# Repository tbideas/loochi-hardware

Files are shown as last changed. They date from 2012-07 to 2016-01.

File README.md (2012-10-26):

Hardware source files for TBIdeas lamp
======================================

This github project contains the source file for the different revisions and prototypes of our smart lamp called Illumi and then Loochi.

## License

    Copyright 2012 - TBIdeas.com
    Distributed under the CC-BY-SA license.
    http://creativecommons.org/licenses/by-sa/3.0/

## Loochi v0.4

Third prototype.

This one is very similar to 0.3 but instead of a Bluegiga BLE112 module, we use an Aircable module with its generic firmware (so it does not need any programming). This module is not yet publicly available but will be very soon. Until then, you can contact us if you would like to get some.

In this design, we have also removed the npn/pnp transistors that were used to drive the mosfet. We wanted to compare the performance with and without them.

The communication protocol is labeled as I2C between the BLE module and the attiny but you can also do SPI. We have not really decided which one we will stick to.

### Known problems and limitations

This board was designed before we had time to assemble the 0.3 so the same problem applies on the LED pads, and connections.

## Loochi v0.3

Second complete prototype designed and built by us.

There is only one board with the LED soldered directly on the board. The PCB is intended to be an aluminium core PCB. For prototypes we have used traditional FR4 boards (from the awesome oshpark.com). In any case you absolutely need a pretty big heatsink on the other side of the board.

This board design is a major rework over the previous version. The main goal was to reduce manufacturing cost so that more people could enjoy Loochi. Another major design decision was to drop Wifi. We could write a lot about that but the biggest arguments were: (1) Wifi seriously increases the costs of the solution and (2) the efforts required by the user to set-up a Wifi lamp are important.

Main characteristics:
 * One ATTiny 861A is used to control the current going through the LED and adjust the brightness
 * One BLE112 module from Bluegiga is used for Bluetooth Low Energy communication with the app, it acts as an SPI Master to the Attiny
 * There is no more dedicated chip for the LED PWM (to reduce costs)
 * Ledengin 10W RGGB Led soldered directly on the PCB
 * Funny fact: the board radius is 3.1415925 cm

You will find more information on how this board works in the source code of the AVR. Several versions are provided (with graduating levels of complexity).

We also plan to do a video to explain how it works. If you are interested, let us know and it will probably be done quicker!

### Known problems on the board layout

There are a few known problems on this PCB:
 * The LED footprint is wrong: the first green LED is backwards (stupid mistake when linking pads and signals)
 * The schematic uses the RESET pin of the uController but we decided later on to change that, the mapping used in the software is BSENSE connected to PB5 and BPWM connected to PB4 (which means the Blue PWM output is inverted but allows us to keep the RESET pin free)
 * The BLE112 module is very sensitive to the quality of the power supply, add an RC filter on its VCC
 * Remove Q4 and short its source and drain (otherwise you will get a shortcut) - Warning: this removes the reverse voltage protection

If you want to make your own, we suggest that you fix those before getting the board manufactured or wait for a new design from us that would not have those problems. Another option is always to cut some traces and put some small wires. This is what we have done.

## Illumi v0.2

__Note: We used to call this version Illumi - dont be surprised in the documentation and source code__

This is the first complete prototype completely designed and built by us.

It is a dual-board design: a board with the micro-controller and the Wifi card, and another board with the LED drivers.

Features of the motherboard:

 * Arduino-Leonardo clone running at 8Mhz - Programmable via a ICSP connector or through the USB cable (once the bootloader has been burnt). You can use the Arduino IDE to program it.
 * Wifi module RN-171 from Roving Networks with a wire antenna
 * Bluetooth 4 Low Energy BLE112 module from Bluegiga
 * Only 75mm by 50mm
 * Switching 3.3 V power supply
 
Features of the LED driver

 * Input voltage from ~5V to 20V (depends on the type of LED you want to power) - Compatible with all sorts of high power LEDs
 * Three LT3518 swiching regulator for a 700mA constant current source to drive one RGB led
 * PWM inputs to control the brightness of each component: Red, Green, Blue
 * Shutdown pin to turn off the regulators and save power
 * Three temperature sensors to measure the board temperature

### Files

 * illumi-motherboard.sch: Eagle Schematic for the motherboard
 * illumi-motherboard.sch: Eagle Board for the motherboard
 * illumi-leddriver.sch: Eagle Schematic for the LED Driver
 * illumi-leddriver.sch: Eagle Board for the LED Driver
 * illumi-leddriver.asc: LTSpice simulation for one LT3518 channel 
 * illumi-v0.2-bom.csv: Bill of material - Detailed list of parts with Mouser reference number, price, etc

### Other resources

 * Source code for the motherboard is available in the Github project named "illumi"
 * Configuration files for the Arduino environment to program this board is in the project named "illumi-arduino"
 * Blog articles:
 ** [3D renderings][blog-board3d]
 ** [Pictures of the assembled board][blog-v0.2]

### Known problems and limitations

 * On the motherboard, you must not solder R16 and bridge the pads instead. The idea was to build a low-pass filter with R16 and C13 but the voltage drop on AVCC is too high and the chip is not programmable with R16 in place. Check out [this discussion on electronics stackexchange][stackexchange-avcc] for more info.
 * The LED driver includes a LM317 to provide 3.3V to the three LT3518. Although they dont use much current, bringing a 20V input to 3.3V incurs some serious heat dissipation on the LM317. It works so far but the next designs will use the motherboard voltage regulator for 3.3V

## Illumi v0.1

This is a very cheap to build linear current source for high power RGB LEDs. Find out more and read more on the [blog article][blog-v0.1]. 

## Illumi v0.0

This is the simplest way to drive an RGB light. Those files were produced to prepare a [blog post introducing development for Illumi][blog-v0.0].

## Let's stay in touch!

We hope you will find this information useful! We are open-sourcing all of this in the hope that it will be useful to someone else - if it is, or if you have any question, please contact us: contact THE_AROBASE tbideas.com.

[blog-v0.0]: http://www.tbideas.com/blog/illumi-101-iphone-controlled-rgb-light/
[blog-v0.1]: http://www.tbideas.com/blog/build-an-arduino-shield-to-drive-high-power-rgb-led/
[stackexchange-avcc]: http://electronics.stackexchange.com/questions/36167/understanding-the-avcc-pin-wiring-on-arduinoleonardo-low-pass-filter
[blog-v0.2]: http://www.tbideas.com/blog/some-pictures-of-our-latest-prototype/
[blog-board3d]: http://www.tbideas.com/blog/design-of-the-led-driver/
[contact]: contact@tbideas.com

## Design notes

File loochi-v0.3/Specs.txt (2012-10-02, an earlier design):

Designing Loochi v0.3
=====================

So I am starting work on the next prototype and here are the main characteristics I am going to focus on.

Characteristics:

 * Works for different types of LEDs: 10W to 40W at least, more if possible
 * Wide range of input voltage: min 6v (?) to 20V to drive those LEDs
 * Wifi card on board
 * Wifi configurable (???) <= tbd - sdcard? or better, sound jack!
 * Cheap - cheap - cheap - Should cost less than $60 (including LED) so that we can sell it for 150$

 * The firmware should be easy to upgrade
   -> USB connection with the bootloader (a little complicated)
   -> Custom bootloader that uses the RN171 to download firmware - quite complicated too
   -> Custom bootloader that loads from a SD Card the firmware

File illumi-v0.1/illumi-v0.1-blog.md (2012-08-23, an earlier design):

# Build an Arduino shield to drive high-power RGB LED

If you have read our [previous post][previous-post], you know how easy it is to connect a RGB led to an Arduino micro-controller. It is amazing to put this thing in a corner of your room and change the color during the night but chances are ... you will be the only one impressed by that.

The [very basic LED][datasheet] we used in our previous post has a power of 45mW (go ahead, take the [datasheet][datasheet] and do the math, it is an interesting exercice, post your results below!) and generates less than one lumen of [luminous flux][lumen]. This is not enough to light anything so you will quickly want to use much more powerful LEDs.

In this post, we will see how to build a very cheap linear LED driver and plug it to our Arduino so that you can actually drive high power RGB LED with the same software we used last time. This time, it gets impressive!

<!--more-->

# Choosing an high-power LED

For a while, high power LEDs were 1W or 3W LEDs. Nowadays, you can easily find 10W, 40W or [90W][lzp]. These are the types of LEDs we will focus on today. Because the bigger the better, especially whey you are building interior lighting fixtures like [Illumi][illumi]. 

The most important characteristics to look at are:

* What is the forward voltage of the diode: You will need to supply the LED with at least that voltage;
* What is the forward current of the diode: This is the current that you will need to supply to the diode. This needs to be very carefully regulated because if you let the current go to high, it will burn the LED. That's why we will build a constant current power supply;
* How will I get heat out of the LED.

And then of course, you will look at the light color, or in our case, the light colors because we will be working with RGB lights. Most of what we say might be adapted for single-color LED or four-colors LEDs.

We like the LEDs from LedEngin and for today's purpose, we will use a [LZ4-00MC00 RGB LED]. We highly recommend that you purchase the one that is already soldered onto a small thermal PCB that will help with heat dissipation. You can [find it on mouser.com][mouser-lz4] for $15.

This LED (like all multi-colors LEDs) is actually several LED dice on one chip. If you take a look at the [datasheet][lz4-datasheet], you will see that the maximum forward voltage for the red, green, and blue dices are 2.96V, 8.32V, 4.48V (the forward voltage for green is actually much higher because there are two green dices in series). We also learn from the datasheet that the nominal forward current is 700 mA, therefore the total power of the LED is 2.96*0.7+8.32*0.7+4.48*0.7=11W.

That is pretty nice compared to our previous sub-watt LED or traditional 1W or 3W led!

Of course, you can pick from other manufacturers, Cree and OSRAM Semiconductors are famous LED manufacturers. Tell us about your experiments in the comments!

# Choosing a current source

The usual technique of putting a current limiting resistor on this type of LED will not work for two reasons. The first one is that the heat dissipated by this resistor would be huge (`P = I * U = 700mA * (Vin - Vf)` = a few watts) but mostly the forward voltage will decrease as the LED heats up and therefore the voltage on the series resistor will be increased which will in turn increase the intensity of the current and the light will not be stable at all. 

You could go on google and purchase a current source but they are usually kind of big and very expensive ($20). Knowing that we need three of them, we ruled this solution out.

So the best solution is to build your own, and we will see how to build one for a couple of dollars.

# A simple linear current source

The schema we introduce here uses a mosfet transistor that is controlled by a feedback mechanism through a current-sense resistor. It is heavily inspired by [Dan Goldwater][dangoldwater] ([MonkeyLectric][monkeylectric]) work posted on [Instructables][instructables].

Linear current source

The parts on this schematic are available for a few dollars. You can replace the BUZ71 by another MOSFET N-channel transistor in a TO220 package. Make sure it can switch 40V to be on the safe side.
For an RGB LED, we will build this three times: once for each channel.

## Let's discuss the schematics

When the PWM input (which will be driven by your micro-controller) is low, then Q1 is not conducting and nothing happens. The LED does not get any current and does not light up.

Things get interesting when you raise the PWM input HIGH (+5V), at this point current will start to flow through R1 and the gate of Q1 and it will let current flow from the source to the drain, therefore turning on the LED.

As current flows through the LED, the voltage drop of R2 increases (remember, U=RI) and when it reaches 0.5V (the forward junction drop of T1),  T1 will start conducting and current from R1 will flow through T1 instead of flowing through Q1, which will reduce the current going through Q1 and the LED.
This circuit will stabilize so that the voltage on R2 is the forward junction drop of T1 and that is how we can control the current going through the LED.

This is a very simple but very efficient schematics that you can use to power any type of LED.

## Setting the current through the LED

One of the crucial component on this schematic is R2. In our example R2 is 0.82 ohm which means that the current in R2 and the LED will reach 610mA (0.5V / 0.82ohm) before it starts turning on T1.
For 610mA, the power dissipated by R2 will be around 0.4W make sure to get a 1/2W or 1W resistor!

Depending on the maximum current you want in your LED, you will adapt the value of R2.

## Heat

If you look at voltage in the circuit, you can easily see that:

    V+ = Vled + Vq1 + Vr1

In this formula, we know V+, Vled and Vr1. V+ is your input voltage, Vled is the forward drop of the LED and Vr1 is 0.5V, the voltage needed to start turning on T1. So let us rewrite the formula as:

    Vq1 = V+ - Vled - Vr1

With an input voltage of 12V and a forward drop of 9V, we will have:

    Vq1 = 12 - 9 - 0.5 = 2.5V
    
We also know that the current going through the circuit is 610mA, therefore the power dissipated in Q1 is:

    Pq1 = Vq1 * Iq1 = 1.5W

## Best case scenario

From the formula above, we can deduce that the circuit is very efficient when Vq1 is equal to 0V, that is when V+ is equal to the forward voltage drop of the LED plus 0.5V. Anything above that on the input will be dissipated as heat in Q1.

Do note also that as things heat up, the forward voltage of the led will reduce a little bit, as well as T1 junction forward voltage (a few hundreds of milli-volts).

## Powering RGB Leds

Let's get back to the value of our LED. We have seen that the forward voltage is not the same for all colors. But you will very likely have only one power supply providing one common voltage to all the LEDs. Therefore there will be some heat dissipation and the bigger the difference in forward voltage, the bigger will be the heat dissipation.

For the LED we suggested above, you can choose to not put both green LEDs in series and power only one, this will reduce the voltage drop difference between red, green and blue and will avoid wasting too much power in the red and blue current sources.

# Build your Arduino high power RGB led shield

So now that we have a schematics that works (I hope you have tried it on your experimentation boards!), you can turn that into an Arduino shield with just a little effort. 

Here is an exemple of what it might look like on a pre-etched PCB:

Arduino High power LED shield

Note that I have added heatsinks (and thermal paste) to the mosfet transistors. Even a few watts of power dissipated will heat the transistor pretty fast. Without heatsinks, they will not last long.

# More power!

If you are using higher power LEDs (or just more LEDs in series), the current will probably be the same but the voltage drop will be higher (that is because high power LEDs are actually more LEDs in series). Therefore the difference in drop between the different color will be even bigger and you will not be able to power them all from the same power supply. You have reached the limit of our linear current source.

The next step is to use a switching power supply that will be much more efficient, whatever the input voltage is. Our [design for Illumi v0.2][illumi-driver-v0.2] provides exactly that!

[previous-post]: http://www.tbideas.com/blog/illumi-101-iphone-controlled-rgb-light
[datasheet]: https://www.sparkfun.com/datasheets/Components/YSL-R596CR3G4B5C-C10.pdf
[lumen]: http://en.wikipedia.org/wiki/Lumen_(unit)
[lzp]: http://www.ledengin.com/products/emitters#LZP
[illumi]: http://www.tbideas.com
[mouser-lz4]: http://www.mouser.com/ProductDetail/LedEngin/LZ4-20MC00/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
[lz4-datasheet]: http://www.ledengin.com/files/products/LZ4/LZ4-00MC00.pdf
[instructables]: http://www.instructables.com/id/Circuits-for-using-High-Power-LED-s/step8/a-little-micro-makes-all-the-difference/
[dangoldwater]: http://www.instructables.com/member/dan/
[monkeylectric]: http://www.monkeylectric.com/
[illumi-driver-v0.2]: http://www.tbideas.com/blog/design-of-the-led-driver/

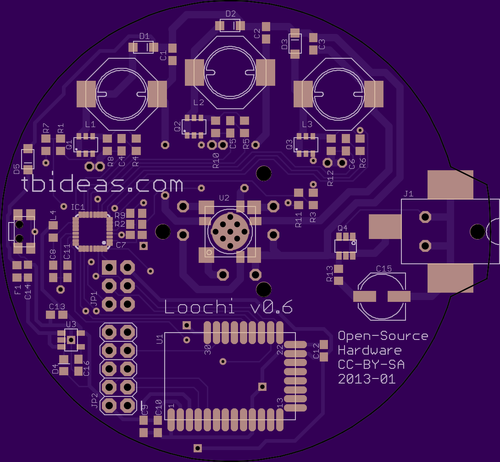
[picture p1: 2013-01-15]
loochi-v0.6/eagle/laenpcb-20130103a/board-top.png

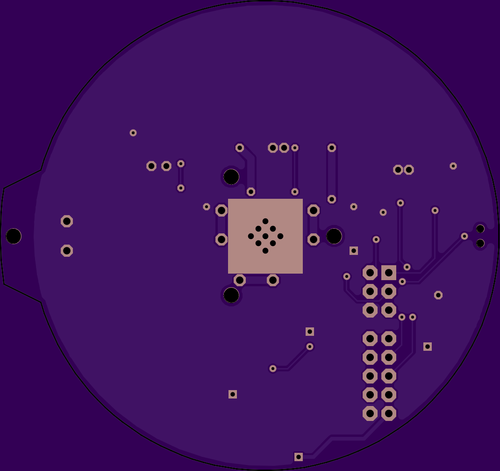
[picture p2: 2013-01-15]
loochi-v0.6/eagle/laenpcb-20130103a/board-bottom.png

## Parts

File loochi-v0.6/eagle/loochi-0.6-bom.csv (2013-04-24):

Part | Description | Package | Manufacturer | Mnf. Ref. | Mouser Ref | Qty | Price per unit ($) | Price /1000
C1,C2,C3 | 4.7uF | C-EUC0603 |  |  | 603-CC603KRX5R6BB475 | 3 | 0.09 | 0.023
C4,C5,C6,C16 (was C17) | 10nF | C-EUC0603 |  |  | 77-VJ0603Y103KXAAC | 4 | 0.06 | 0.016
C7,C8,C11,C14 | 0.1uF | C-EUC0603 |  |  | 77-VJ0603Y104JXJPBC | 4 | 0.06 | 0.012
C9,C10,C12 | 1uF | C-EUC0603 |  |  | 77-VJ0603V105MXQPBC | 3 | 0.06 | 0.009
C13 (was C14) | 10u | C-EUC0603 |  |  | 810-C1608X5R0J106M | 1 | 0.12 | 0.053
C15 (was C16) | 100uF | CPOL-EUD |  |  | 598-AVE107M25X16T-F | 1 | 0.13 | 0.066
D1,D2,D3,D5 | Schottky PMEG4010CEH | SOD123F |  |  | 771-PMEG4010CEH-T/R | 3 | 0.11 | 0.081
D4 | Schottky0603 | D0603 | Bourns |  | 652-CD0603-B00340 | 1 | 0.12 | 0.06
F1 | MPZ1608 | R-EU_R0603 |  |  | 810-MPZ1608S221A | 1 | 0.05 | 0.019
IC1 | ATTINY61M | ATTINY61M | MLF32 |  | 556-ATTINY861V10MU | 1 | 3.03 | 1.72
J1 (was J2) | SMD Power connector | POWER-JACK |  | KLDXSMT30202BTR | 806-KLDXSMT30202BTR | 1 | 1.61 | 1.05
JP1 (was J1) | SPI_PRG | AVR_SPI_PRG_6NS | 2X3-NS |  | 649-68602-406HLF | 1 | 0.12 | 0
JP2 | Molex 5x2 |  |  |  | 649-68602-110HLF | 1 | 0.3 | 0.15
L1,L2,L3 | SRU1038-101Y | L-USBOURNS-SRU1038 |  |  | 652-SRU1038-101Y | 3 | 0.58 | 0.32
L4 | 10uH | L-USL0603 |  |  | 810-MLZ1608M100W | 1 | 0.08 | 0.037
Q1,Q2,Q3 | PMN25ENSOT457 | PMN25ENSOT457 |  |  | 771-PMN25EN,115 | 3 | 0.14 | 0.095
Q4 | FDC654P | SUPERSOT6 | Fairchild Semi. | FDC654P | 512-FDC654P | 1 | 0.25 | 0.12
R1,R2,R3 | 10 | R-EU_R0603 |  |  | 652-CR0603-FX10R0GLF | 3 | 0.04 | 0.008
R4,R5,R6,R7,R9,R11 | 10k | R-EU_R0603 |  |  | 652-CR0603-FX1002HLF | 6 | 0.04 | 0.008
R8,R10,R12 | 0.1 | R-EU_R0603 |  |  | CRL0603-FW-R100ELF | 3 | 0.08 | 0.054
R13 (was R15) | 2 | R-EU_R0603 |  |  | 301-2.0-RC | 1 | 0.03 | 0.013
S1 |  |  |  |  | 611-KMS221GLFS | 1 | 0.29 | 0.25
U1 | Ble 112 |  |  |  | 603-BLE112-A | 1 | 17.5 | 15.9
U2 (was U1) | LZ4-00MC00 |  | Ledengin | LZ4-00MC00 | 897-LZ400MC00 | 1 | 11.52 | 9.25
U3 (was U$2) | LP2985 | LP2985 |  |  | 595-LP2985-33DBVR | 1 | 0.46 | 0.192
Heatsink |  |  | Lighting Science Group | HS-4075-0345 | 599-HS-4075-0345 | 1 | 19.21 | 15.99
Total |  |  |  |  |  |  | 58.84 | 46.8

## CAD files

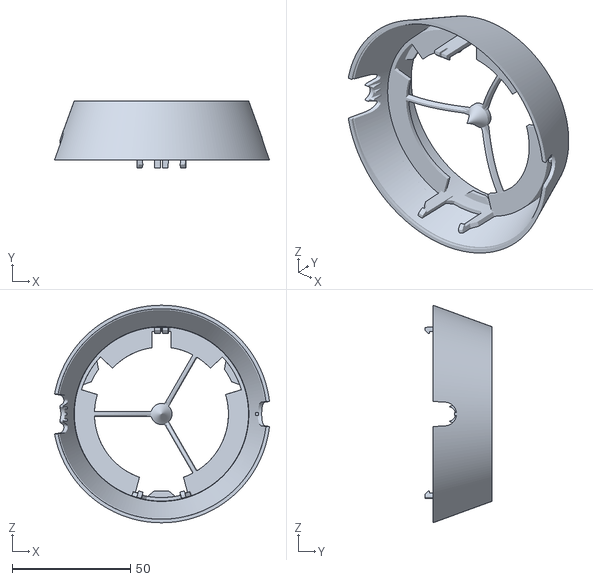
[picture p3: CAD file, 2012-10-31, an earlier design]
loochi-v0.4/Plastic/Loochi_Design/ShadeMount_E.STL
90.9 x 28.5 x 92.0

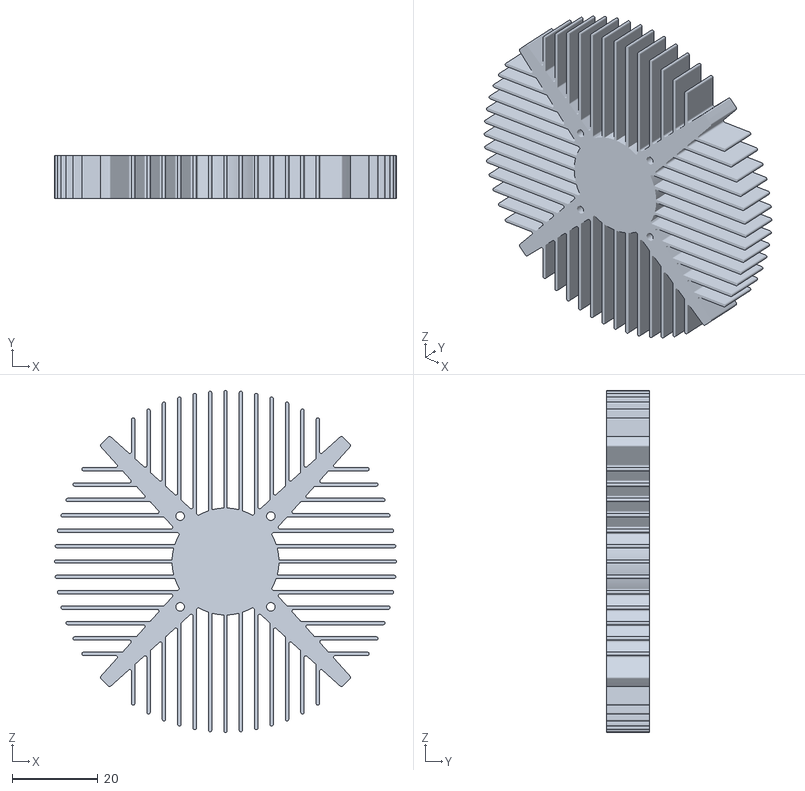
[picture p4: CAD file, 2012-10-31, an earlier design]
loochi-v0.4/Plastic/Loochi_Design/HeatSink_E.STL
80.0 x 10.0 x 80.0

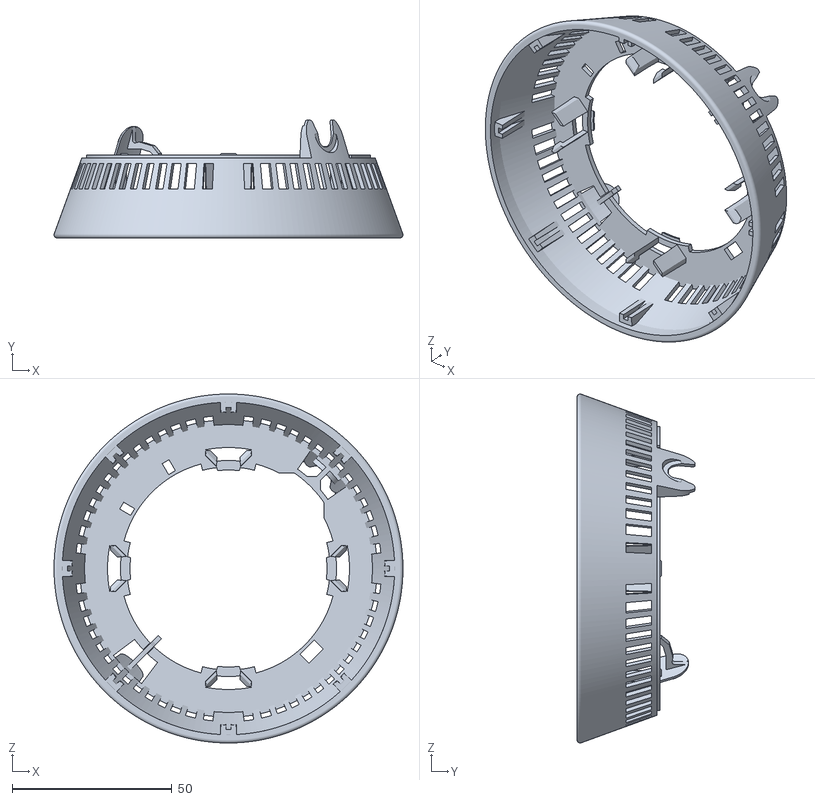
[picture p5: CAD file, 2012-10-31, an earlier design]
loochi-v0.4/Plastic/Loochi_Design/Bridge_E.STL
109.3 x 37.0 x 109.3

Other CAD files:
loochi-v0.6/plastic/loochi.f3d

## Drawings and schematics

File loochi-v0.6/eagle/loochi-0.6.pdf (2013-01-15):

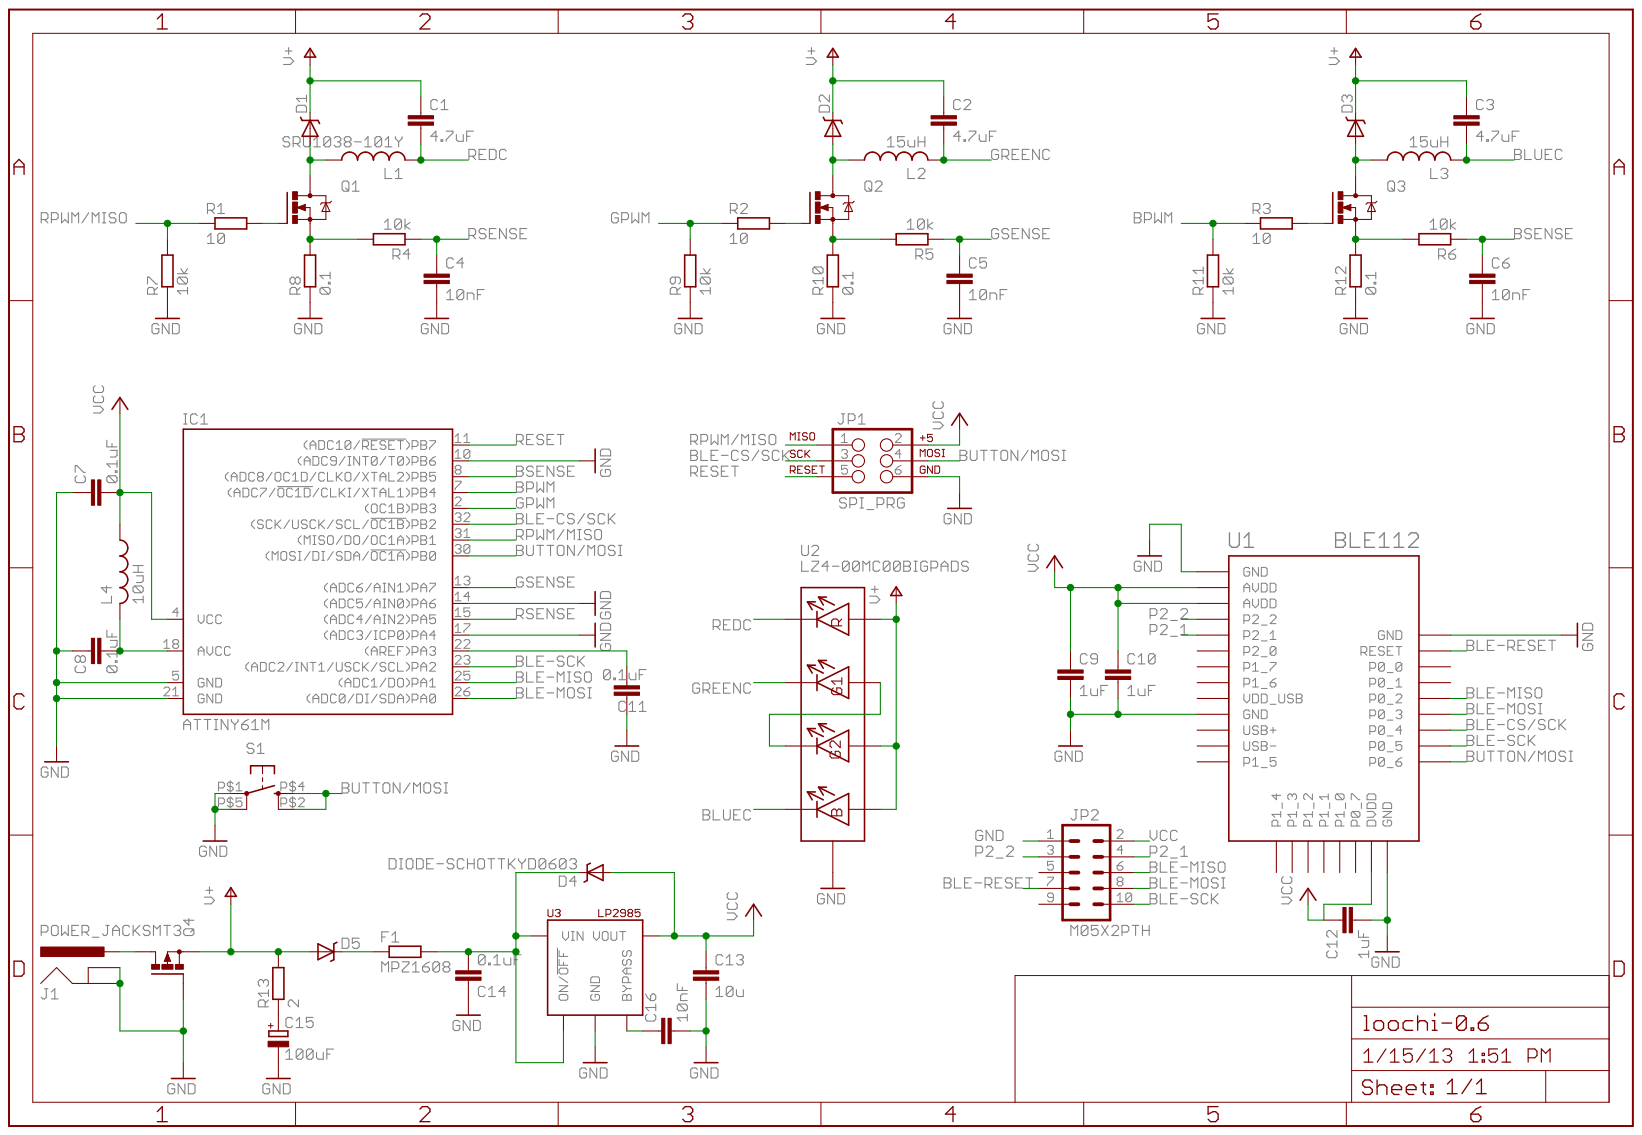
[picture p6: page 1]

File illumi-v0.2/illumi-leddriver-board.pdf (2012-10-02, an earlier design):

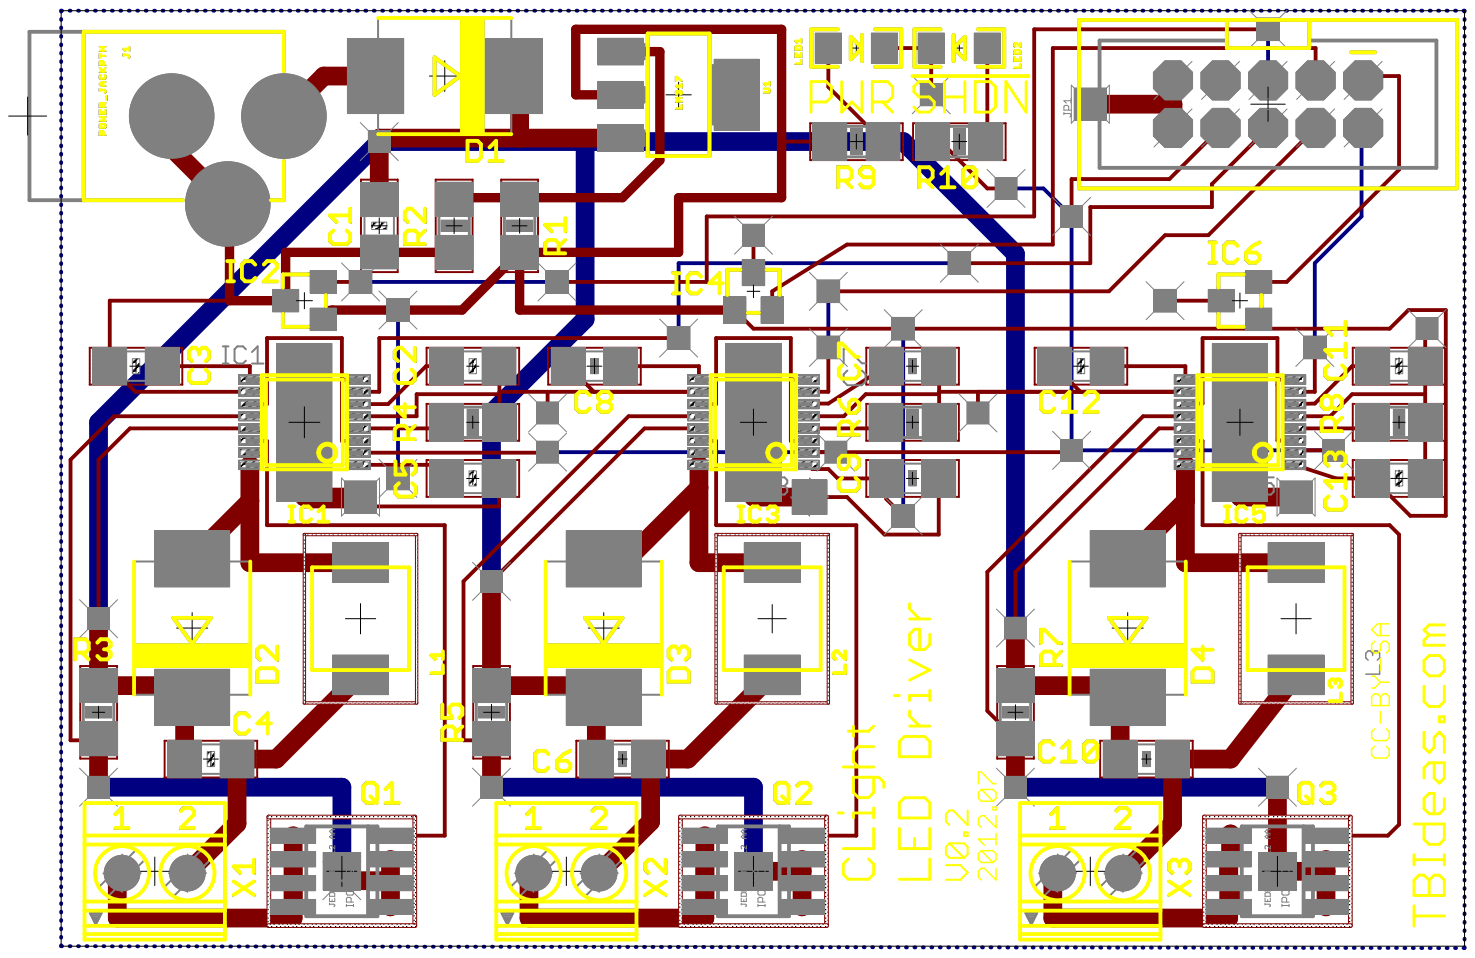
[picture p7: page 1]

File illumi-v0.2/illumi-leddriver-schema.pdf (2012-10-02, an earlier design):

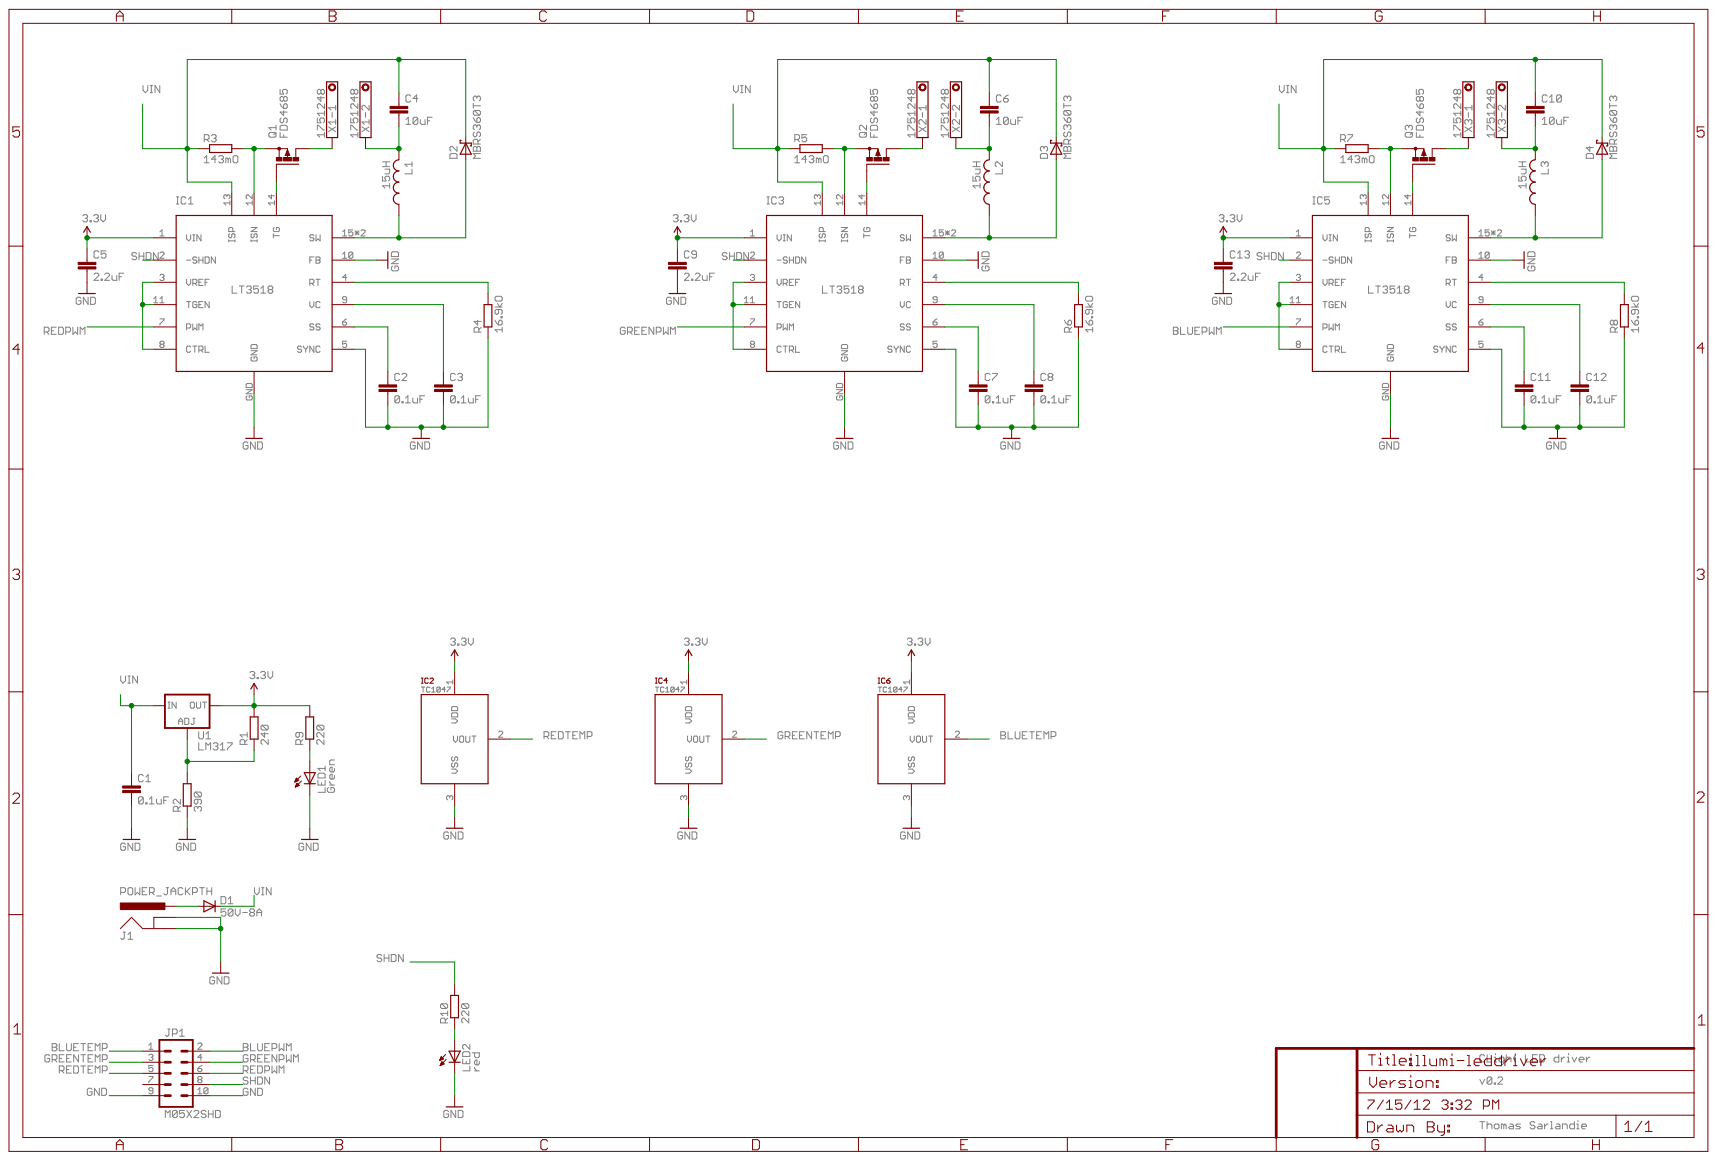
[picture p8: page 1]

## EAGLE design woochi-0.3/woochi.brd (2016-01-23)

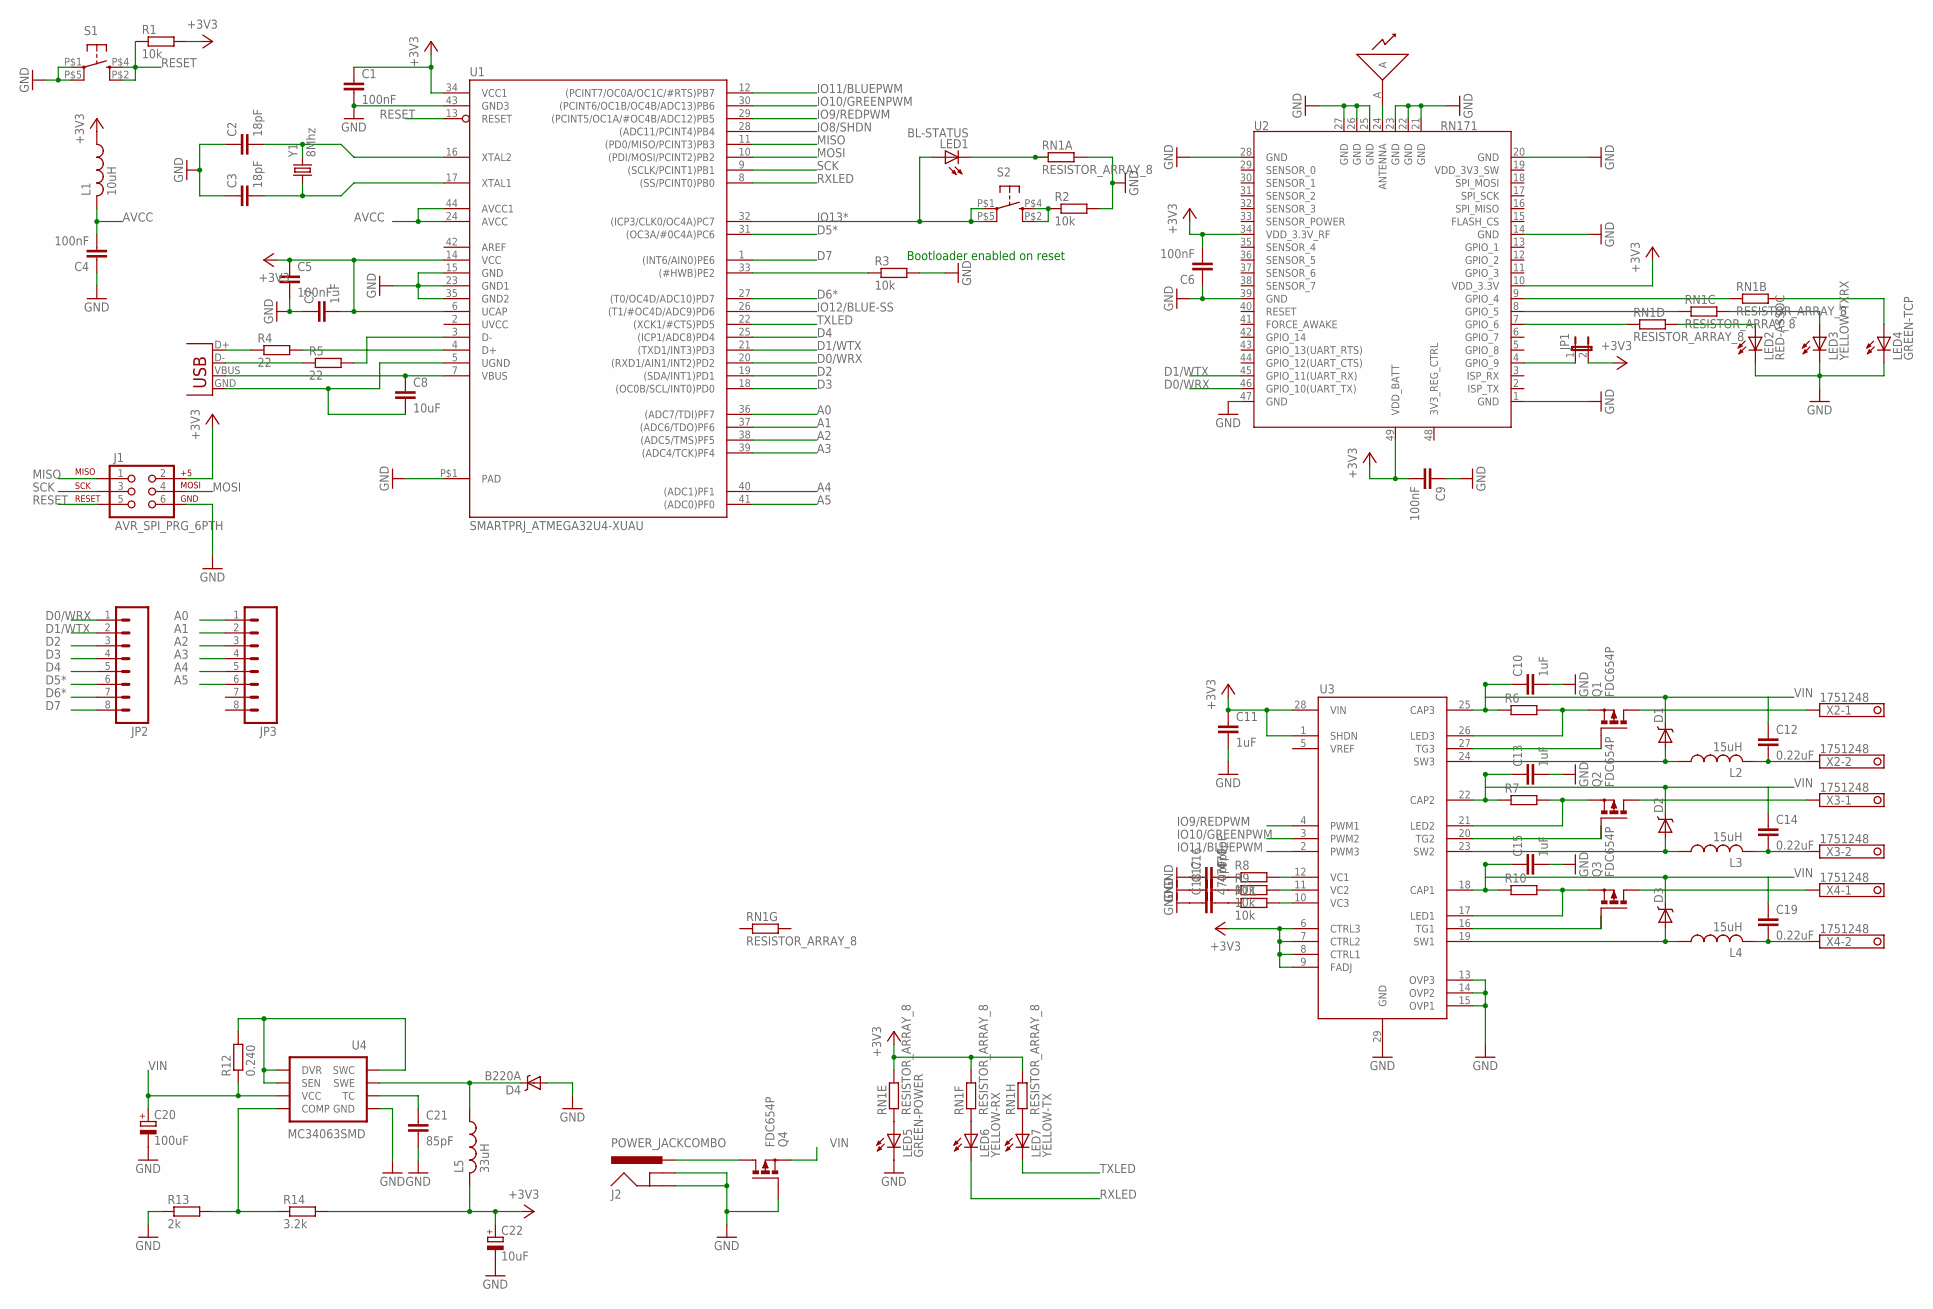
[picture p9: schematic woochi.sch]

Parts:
A1: ANTENNAWIRE; ANTENNA-WIRE
C1, C4, C5, C6, C9: 100nF; C0603
C2, C3: 18pF; C0603
C7, C10, C11, C13, C15: 1uF; C0603
C8: 10uF; C0603
C12, C14, C19: 0.22uF; C0603
C16, C17, C18: 470pF; C0603
C20: 100uF; PANASONIC_D
C21: 85pF; C0603
C22: 10uF; PANASONIC_C
D1, D2, D3: DIODE-SCHOTTKYBIGPAD; SMA-DIODE-BIG
D4: B220A; SMA-DIODE-BIG
J1: AVR_SPI_PRG_6PTH; 2X3
J2: POWER_JACKCOMBO; POWER_JACK_COMBO
JP1: JUMPER-2PTH; 1X02
JP2, JP3: M081X08; 1X08
L1: 10uH; L0603
L2, L3, L4: 15uH; BOURNS-6045
L5: 33uH; BOURNS-6045
LED1: BL-STATUS; SML0603
LED2: RED-ASSOC; SML0603
LED3: YELLOW-TXRX; SML0603
LED4: GREEN-TCP; SML0603
LED5: GREEN-POWER; SML0603
LED6: YELLOW-RX; SML0603
LED7: YELLOW-TX; SML0603
Q1, Q2, Q3, Q4: FDC654P; SUPERSOT6
R1, R2, R3, R8, R9, R11: 10k; R0603
R4, R5: 22; R0603
R6, R7, R10: R-EU_R0603; R0603
R12: 0.240; R0603
R13: 2k; R0603
R14: 3.2k; R0603
RN1: RESISTOR_ARRAY_8; CAT16-F8/CAT16-J8
S1, S2: TAC_SWITCH; CK-KMS_PEGS
U1: SMARTPRJ_ATMEGA32U4-XUAU; SMARTPRJ_TQFP44-PAD
U2: RN171; MODULE_49P-1.27-26.67X17.78
U3: LT3496; SSOP28_THERMAL
U4: MC34063SMD; SO08
X1: USB-MICROB
X2, X3, X4: 1751248
Y1: 8Mhz; HC49UP

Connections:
+3V3: C1.1, C5.1, C6.2, C7.2, C9.2, C11.1, C22.+, J1.2, JP1.2, L1.1, L5.P$2 (2), R1.2, R14.2, RN1.9 (2), RN1.11 (2), RN1.12 (2), U1.6 (UCAP), U1.14 (VCC), U1.34 (VCC1), U2.10 (VDD_3.3V), U2.34 (VDD_3.3V_RF), U2.49 (VDD_BATT), U3.1 (SHDN), U3.6 (CTRL3), U3.7 (CTRL2), U3.8 (CTRL1), U3.9 (FADJ), U3.28 (VIN)
A0: JP3.1, U1.36 ((ADC7/TDI)PF7)
A1: JP3.2, U1.37 ((ADC6/TDO)PF6)
A2: JP3.3, U1.38 ((ADC5/TMS)PF5)
A3: JP3.4, U1.39 ((ADC4/TCK)PF4)
A4: JP3.5, U1.40 ((ADC1)PF1)
A5: JP3.6, U1.41 ((ADC0)PF0)
AREF: U1.42 (AREF)
AVCC: C4.2, L1.2, U1.24 (AVCC), U1.44 (AVCC1)
D0/WRX: JP2.1, U1.20 ((RXD1/AIN1/INT2)PD2), U2.46 (GPIO_10(UART_TX))
D1/WTX: JP2.2, U1.21 ((TXD1/INT3)PD3), U2.45 (GPIO_11(UART_RX))
D2: JP2.3, U1.19 ((SDA/INT1)PD1)
D3: JP2.4, U1.18 ((OC0B/SCL/INT0)PD0)
D4: JP2.5, U1.25 ((ICP1/ADC8)PD4)
D5*: JP2.6, U1.31 ((OC3A/#0C4A)PC6)
D6*: JP2.7, U1.27 ((T0/OC4D/ADC10)PD7)
D7: JP2.8, U1.1 ((INT6/AIN0)PE6)
GND: C1.2, C2.1, C3.1, C4.1, C5.2, C6.1, C7.1, C9.1, C10.2, C11.2, C13.2, C15.2, C16.1, C17.1, C18.1, C20.-, C21.2, C22.-, D4.A, J1.6, J2.GND (GNDBREAK), J2.GND@1 (GND), LED2.C, LED3.C, LED4.C, LED5.C, Q4.P$3 (G), R2.2, R3.2, R13.1, RN1.16 (2), S1.P$1 (1), S1.P$5 (2), U1.15 (GND), U1.23 (GND1), U1.35 (GND2), U1.43 (GND3), U1.P$1 (PAD), U2.1 (GND), U2.14 (GND), U2.20 (GND), U2.21 (GND), U2.22 (GND), U2.23 (GND), U2.25 (GND), U2.26 (GND), U2.27 (GND), U2.28 (GND), U2.39 (GND), U2.47 (GND), U3.13 (OVP3), U3.14 (OVP2), U3.15 (OVP1), U3.29 (GND), U4.4 (GND)
IO8/SHDN: U1.28 ((ADC11/PCINT4)PB4)
IO9/REDPWM: U1.29 ((PCINT5/OC1A/#OC4B/ADC12)PB5), U3.4 (PWM1)
IO10/GREENPWM: U1.30 ((PCINT6/OC1B/OC4B/ADC13)PB6), U3.3 (PWM2)
IO11/BLUEPWM: U1.12 ((PCINT7/OC0A/OC1C/#RTS)PB7), U3.2 (PWM3)
IO12/BLUE-SS: U1.26 ((T1/#OC4D/ADC9)PD6)
IO13*: LED1.A, S2.P$1 (1), S2.P$5 (2), U1.32 ((ICP3/CLK0/OC4A)PC7)
MISO: J1.1, U1.11 ((PD0/MISO/PCINT3)PB3)
MOSI: J1.4, U1.10 ((PDI/MOSI/PCINT2)PB2)
unnamed: LED5.A, RN1.5 (1)
unnamed: A1.A, U2.24 (ANTENNA)
unnamed: RN1.2 (1), U2.9 (GPIO_4)
unnamed: RN1.3 (1), U2.8 (GPIO_5)
unnamed: RN1.4 (1), U2.7 (GPIO_6)
unnamed: LED2.A, RN1.13 (2)
unnamed: LED3.A, RN1.14 (2)
unnamed: LED4.A, RN1.15 (2)
unnamed: C8.2, U1.5 (UGND), X1.GND
unnamed: R4.1, X1.D+
unnamed: JP1.1, U2.4 (GPIO_9)
unnamed: R5.1, X1.D-
unnamed: C8.1, U1.7 (VBUS), X1.VBUS
unnamed: R4.2, U1.4 (D+)
unnamed: R5.2, U1.3 (D-)
unnamed: LED1.C, RN1.1
unnamed: LED6.A, RN1.6 (1)
unnamed: LED7.A, RN1.8 (1)
unnamed: R3.1, U1.33 ((#HWB)PE2)
unnamed: R12.2, U4.1 (SWC), U4.7 (SEN), U4.8 (DVR)
unnamed: J2.POWER (PWR), Q4.P$1 (D), Q4.P$2 (D), Q4.P$5 (D), Q4.P$6 (D)
unnamed: D4.C, L5.P$1 (1), U4.2 (SWE)
unnamed: R2.1, S2.P$2 (4), S2.P$4 (3)
unnamed: C21.1, U4.3 (TC)
unnamed: R13.2, R14.1, U4.5 (COMP)
unnamed: C12.2, L2.P$2 (2), X2.2
unnamed: Q1.P$4 (S), R6.2, U3.26 (LED3)
unnamed: D1.A, L2.P$1 (1), U3.24 (SW3)
unnamed: Q2.P$4 (S), R7.2, U3.21 (LED2)
unnamed: Q1.P$1 (D), Q1.P$2 (D), Q1.P$5 (D), Q1.P$6 (D), X2.1
unnamed: Q1.P$3 (G), U3.27 (TG3)
unnamed: C14.2, L3.P$2 (2), X3.2
unnamed: R11.2, U3.10 (VC3)
unnamed: R9.2, U3.11 (VC2)
unnamed: R8.2, U3.12 (VC1)
unnamed: C16.2, R8.1
unnamed: C17.2, R9.1
unnamed: C18.2, R11.1
unnamed: D2.A, L3.P$1 (1), U3.23 (SW2)
unnamed: Q2.P$3 (G), U3.20 (TG2)
unnamed: Q2.P$1 (D), Q2.P$2 (D), Q2.P$5 (D), Q2.P$6 (D), X3.1
unnamed: Q3.P$4 (S), R10.2, U3.17 (LED1)
unnamed: C19.2, L4.P$2 (2), X4.2
unnamed: D3.A, L4.P$1 (1), U3.19 (SW1)
unnamed: Q3.P$3 (G), U3.16 (TG1)
unnamed: Q3.P$1 (D), Q3.P$2 (D), Q3.P$5 (D), Q3.P$6 (D), X4.1
RESET: R1.1, S1.P$2 (4), S1.P$4 (3), U1.13 (RESET)
RXLED: LED6.C, U1.8 ((SS/PCINT0)PB0)
SCK: J1.3, U1.9 ((SCLK/PCINT1)PB1)
TXLED: LED7.C, U1.22 ((XCK1/#CTS)PD5)
UVCC: U1.2 (UVCC)
VIN: C10.1, C12.1, C13.1, C14.1, C15.1, C19.1, C20.+, D1.C, D2.C, D3.C, Q4.P$4 (S), R6.1, R7.1, R10.1, R12.1, U3.18 (CAP1), U3.22 (CAP2), U3.25 (CAP3), U4.6 (VCC)
XTAL1: C3.2, U1.17 (XTAL1), Y1.1
XTAL2: C2.2, U1.16 (XTAL2), Y1.2

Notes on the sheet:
Bootloader enabled on reset

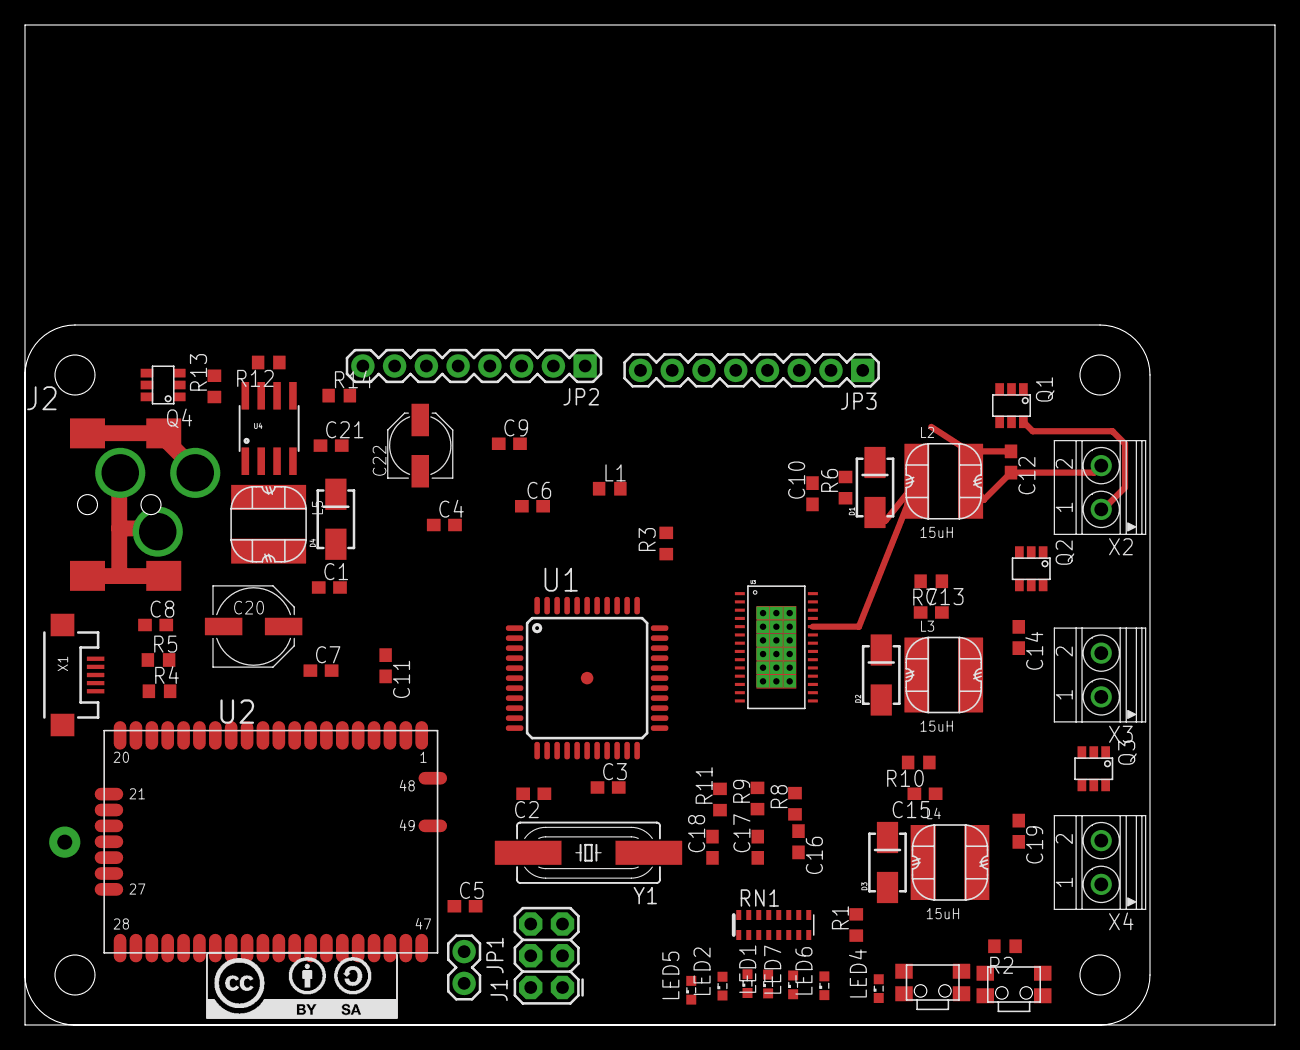
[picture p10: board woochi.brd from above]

Board: 2 copper layers, 100.0 x 80.0 mm, 76 parts (0 on the bottom side), 76 nets.

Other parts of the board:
U$1: DP9056_V1
U$2: LOGO_CC-BY-SA

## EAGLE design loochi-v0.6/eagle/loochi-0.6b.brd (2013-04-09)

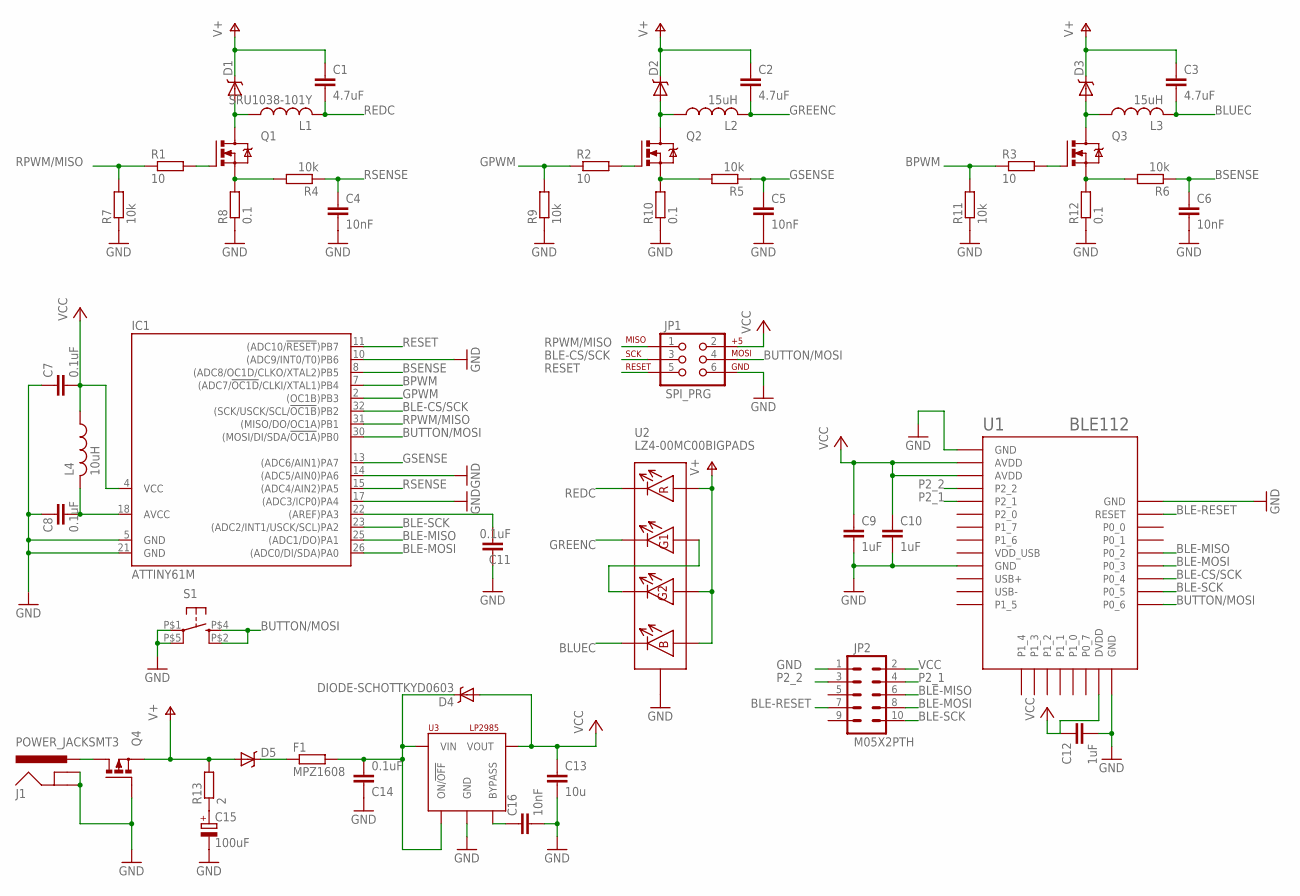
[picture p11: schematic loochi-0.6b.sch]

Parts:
C1, C2, C3: 4.7uF; C0603
C4, C5, C6, C16: 10nF; C0603
C7, C8, C11: 0.1uF; C0603
C9, C10, C12: 1uF; C0603
C13: 10u; C0603
C14: 0.1uF; C0603K
C15: 100uF; PANASONIC_D
D1, D2, D3, D5: PMEG4010CEH; SOD123F
D4: DIODE-SCHOTTKYD0603; D0603
F1: MPZ1608; R0603
IC1: ATTINY61M; MLF32
J1: POWER_JACKSMT3; POWER-KYCONSMT3
JP1: SPI_PRG; 2X3-NS
JP2: M05X2PTH; AVR_ICSP
L1: SRU1038-101Y; BOURNS-SRU1038
L2, L3: 15uH; BOURNS-SRU1038
L4: 10uH; L0603
Q1, Q2, Q3: PMN25ENSOT457; SOT457
Q4: FDC654P; SUPERSOT6
R1, R2, R3: 10; R0603
R4, R5, R6, R7, R9, R11: 10k; R0603
R8, R10, R12: 0.1; R0603
R13: 2; R0603
S1: TAC_SWITCH; CK-KMS_PEGS
U1: BLE112; SF-BLUEGIGA_BLE112-A
U2: LZ4-00MC00BIGPADS; LZ4-00MC00-BIGPADS
U3: LP2985; DBV

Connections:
BLE-CS/SCK: IC1.32 ((SCK/USCK/SCL/!OC1B!)PB2), JP1.3, U1.P0_4
BLE-MISO: IC1.25 ((ADC1/DO)PA1), JP2.6, U1.P0_2
BLE-MOSI: IC1.26 ((ADC0/DI/SDA)PA0), JP2.8, U1.P0_3
BLE-RESET: JP2.7, U1.RESET
BLE-SCK: IC1.23 ((ADC2/INT1/USCK/SCL)PA2), JP2.10, U1.P0_5
BLUEC: C3.2, L3.P$2 (2), U2.P$8
BPWM: IC1.7 ((ADC7/!OC1D!/CLKI/XTAL1)PB4), R3.1, R11.2
BSENSE: C6.1, IC1.8 ((ADC8/OC1D/CLKO/XTAL2)PB5), R6.1
BUTTON/MOSI: IC1.30 ((MOSI/DI/SDA/!OC1A!)PB0), JP1.4, S1.P$2 (4), S1.P$4 (3), U1.P0_6
GND: C4.2, C5.2, C6.2, C7.1, C8.1, C9.2, C10.2, C11.1, C12.2, C13.2, C14.1, C15.-, C16.2, IC1.5 (GND), IC1.10 ((ADC9/INT0/T0)PB6), IC1.14 ((ADC5/AIN0)PA6), IC1.17 ((ADC3/ICP0)PA4), IC1.21 (GND), J1.P$2 (GND), J1.P$3 (GNDBREAK), JP1.6, JP2.1, Q4.P$3 (G), R7.1, R8.1, R9.1, R10.1, R11.1, R12.1, S1.P$1 (1), S1.P$5 (2), U1.GND1 (GND), U1.GND2 (GND), U1.GND3 (GND), U1.GND4 (GND), U2.P$9 (THERMAL), U2.THERMAL, U2.THERMAL1 (THERMAL), U2.THERMAL2 (THERMAL), U2.THERMAL3 (THERMAL), U2.THERMAL4 (THERMAL), U2.THERMAL5 (THERMAL), U2.THERMAL6 (THERMAL), U2.THERMAL7 (THERMAL), U2.THERMAL8 (THERMAL), U2.THERMAL9 (THERMAL), U3.2 (GND)
GPWM: IC1.2 ((OC1B)PB3), R2.1, R9.2
GREENC: C2.2, L2.P$2 (2), U2.P$6
GSENSE: C5.1, IC1.13 ((ADC6/AIN1)PA7), R5.1
unnamed: U2.P$2, U2.P$5
unnamed: Q3.P$3 (G), R3.2
unnamed: Q2.P$3 (G), R2.2
unnamed: Q1.P$3 (G), R1.2
unnamed: D5.P$C (C), F1.1
unnamed: Q1.P$4 (S), R4.2, R8.2
unnamed: D1.P$A (A), L1.P$1 (1), Q1.P$1 (D), Q1.P$2 (D), Q1.P$5 (D), Q1.P$6 (D)
unnamed: C11.2, IC1.22 ((AREF)PA3)
unnamed: J1.P$1 (PWR), Q4.P$1 (D), Q4.P$2 (D), Q4.P$5 (D), Q4.P$6 (D)
unnamed: C8.2, IC1.18 (AVCC), L4.2
unnamed: C16.1, U3.4 (BYPASS)
unnamed: D2.P$A (A), L2.P$1 (1), Q2.P$1 (D), Q2.P$2 (D), Q2.P$5 (D), Q2.P$6 (D)
unnamed: Q2.P$4 (S), R5.2, R10.2
unnamed: C15.+, R13.1
unnamed: C14.2, D4.CATHODE (C), F1.2, U3.1 (VIN), U3.3 (ON/!OFF!)
unnamed: D3.P$A (A), L3.P$1 (1), Q3.P$1 (D), Q3.P$2 (D), Q3.P$5 (D), Q3.P$6 (D)
unnamed: Q3.P$4 (S), R6.2, R12.2
P2_1: JP2.4, U1.P2_1
P2_2: JP2.3, U1.P2_2
REDC: C1.2, L1.P$2 (2), U2.P$4
RESET: IC1.11 ((ADC10/!RESET!)PB7), JP1.5
RPWM/MISO: IC1.31 ((MISO/DO/OC1A)PB1), JP1.1, R1.1, R7.2
RSENSE: C4.1, IC1.15 ((ADC4/AIN2)PA5), R4.1
V+: C1.1, C2.1, C3.1, D1.P$C (C), D2.P$C (C), D3.P$C (C), D5.P$A (A), Q4.P$4 (S), R13.2, U2.P$1, U2.P$3, U2.P$7
VCC: C7.2, C9.1, C10.1, C12.1, C13.1, D4.ANODE (A), IC1.4 (VCC), JP1.2, JP2.2, L4.1, U1.AVDD1 (AVDD), U1.AVDD2 (AVDD), U1.DVDD, U3.5 (VOUT)
VDD_USB: U1.VDD_USB

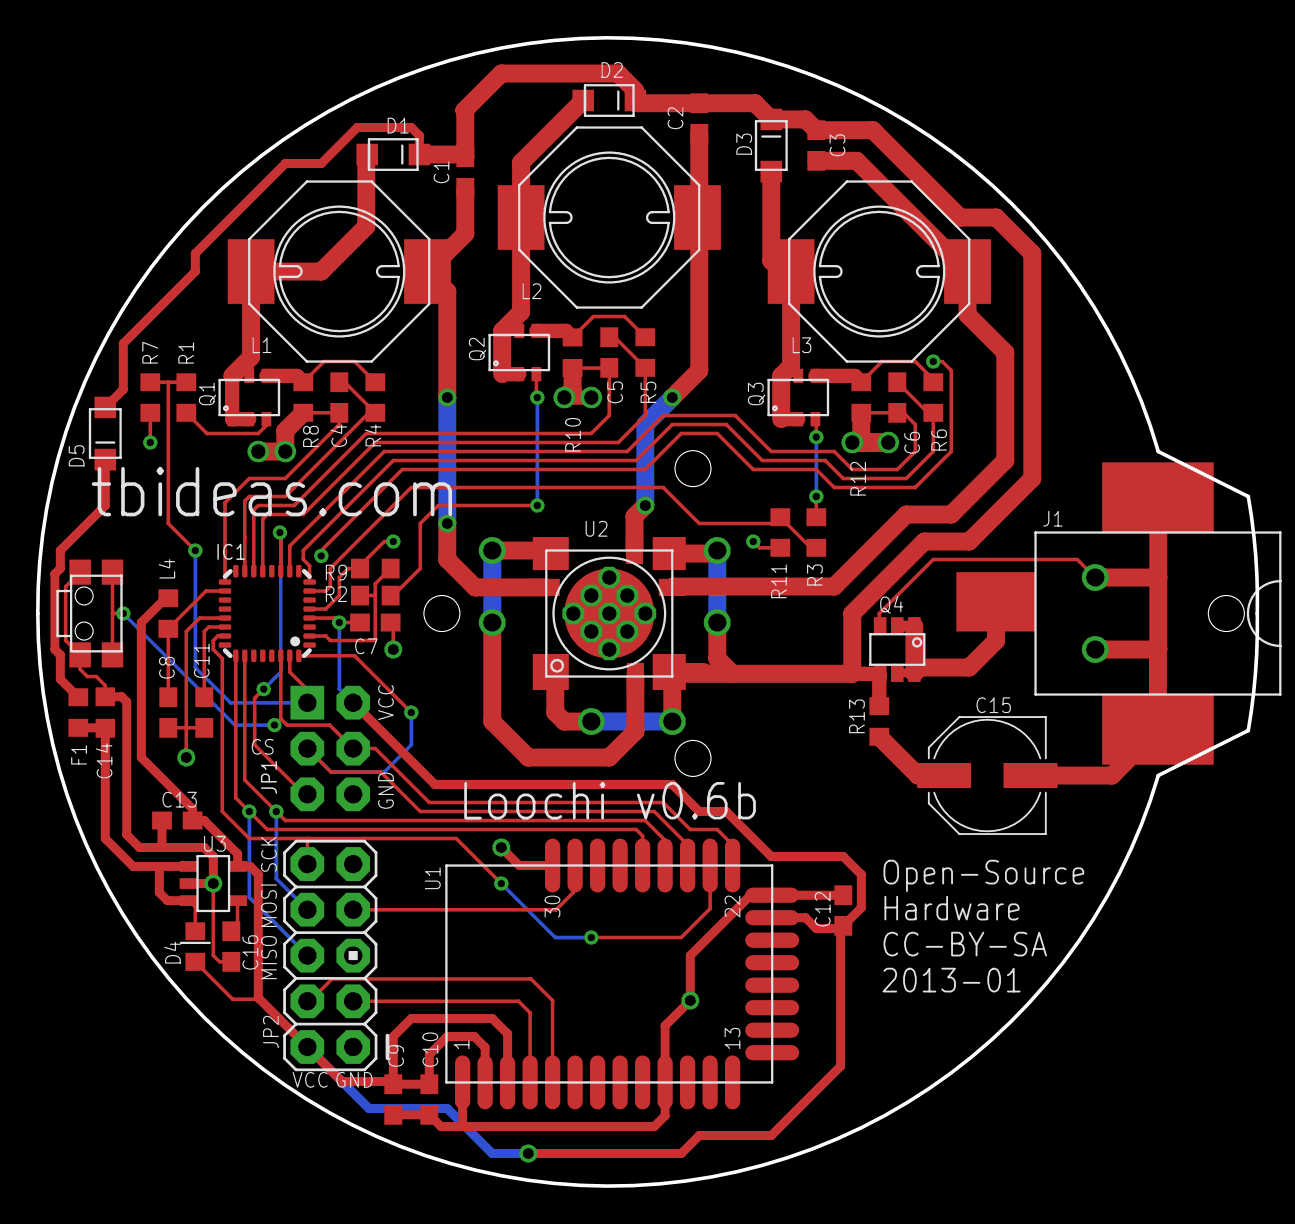
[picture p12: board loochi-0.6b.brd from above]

Board: 2 copper layers, 67.8 x 63.8 mm, 51 parts (0 on the bottom side), 38 nets.

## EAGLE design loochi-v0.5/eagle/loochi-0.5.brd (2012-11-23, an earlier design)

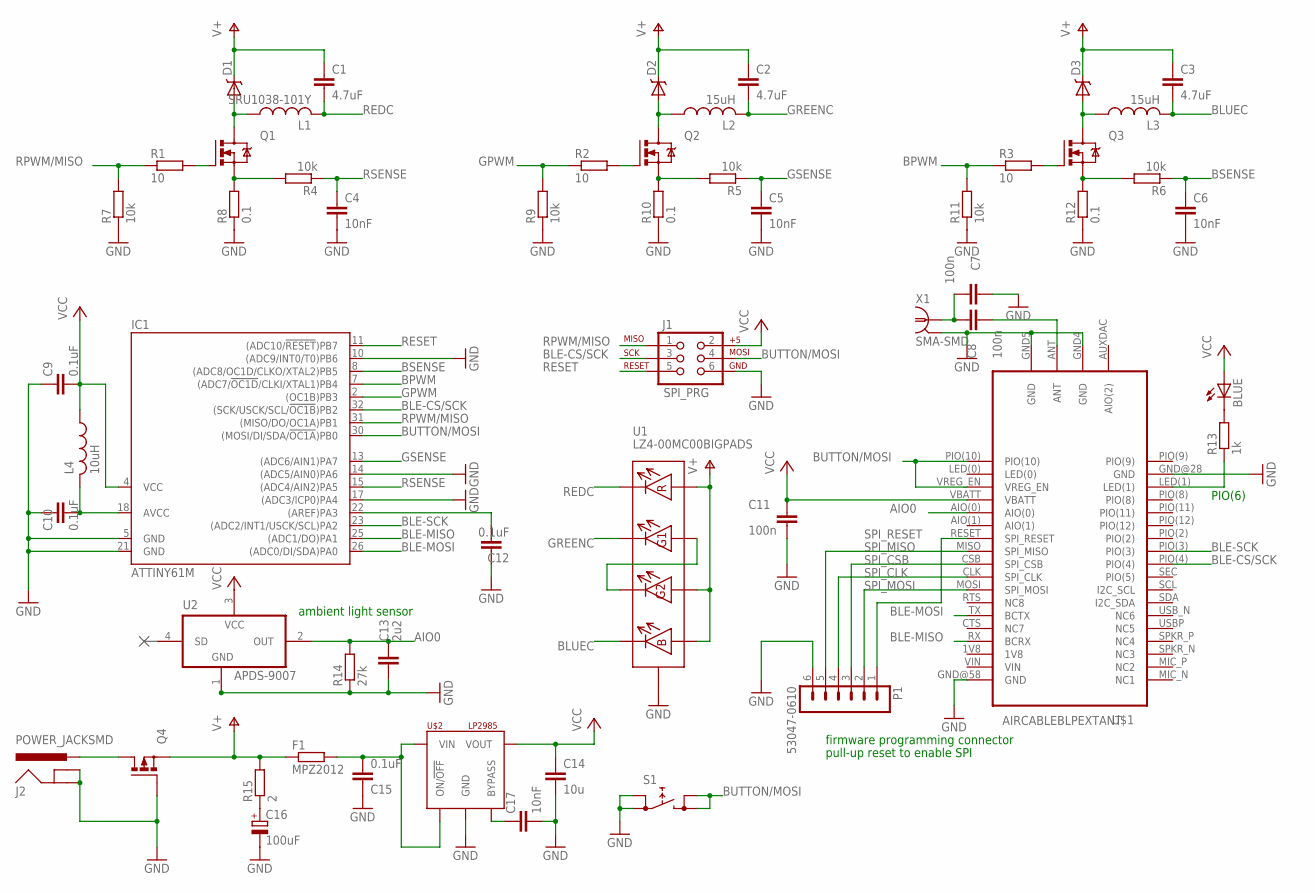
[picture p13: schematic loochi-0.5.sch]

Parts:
BLUE: 500003; CHIPLED_0603
C1, C2, C3: 4.7uF; C0603
C4, C5, C6, C17: 10nF; C0603
C7, C8, C11: 100n; C0603; PARTNO *
C9, C10, C12: 0.1uF; C0603
C13: 2u2; C0603; PARTNO *
C14: 10u; C0603
C15: 0.1uF; C0603K
C16: 100uF; PANASONIC_D
D1, D2, D3: PMEG4010CEH; SOD123F
F1: MPZ2012; R0603
IC1: ATTINY61M; MLF32
J1: SPI_PRG; 2X3-NS
J2: POWER_JACKSMD; POWER_JACK_SMD
L1: SRU1038-101Y; BOURNS-SRU1038
L2, L3: 15uH; BOURNS-SRU1038
L4: 10uH; L0603
P1: 53047-0610; PARTNO *
Q1, Q2, Q3: PMN25ENSOT457; SOT457
Q4: FDC654P; SUPERSOT6
R1, R2, R3: 10; R0603
R4, R5, R6, R7, R9, R11: 10k; R0603
R8, R10, R12: 0.1; R0603
R13: 1k; R0603
R14: 27k; R0603
R15: 2; R0603
S1: REKN; TACTSWITCHHORIZONTAL; PARTNO *
U1: LZ4-00MC00BIGPADS; LZ4-00MC00-BIGPADS
U2: APDS-9007; PARTNO *
U$1: AIRCABLEBLPEXTANT; AIRCABLEBLP
U$2: LP2985; DBV
X1: SMA-SMD

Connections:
AIO0: C13.1, R14.2, U2.2 (OUT), U$1.AIO(0)
BLE-CS/SCK: IC1.32 ((SCK/USCK/SCL/!OC1B!)PB2), J1.3, U$1.PIO(4)
BLE-MISO: IC1.25 ((ADC1/DO)PA1), U$1.RX (BCRX)
BLE-MOSI: IC1.26 ((ADC0/DI/SDA)PA0), U$1.TX (BCTX)
BLE-SCK: IC1.23 ((ADC2/INT1/USCK/SCL)PA2), U$1.PIO(3)
BLUEC: C3.2, L3.P$2 (2), U1.P$8
BPWM: IC1.7 ((ADC7/!OC1D!/CLKI/XTAL1)PB4), R3.1, R11.2
BSENSE: C6.1, IC1.8 ((ADC8/OC1D/CLKO/XTAL2)PB5), R6.1
BUTTON/MOSI: IC1.30 ((MOSI/DI/SDA/!OC1A!)PB0), J1.4, S1.3 (1), S1.4 (1), U$1.PIO(10), U$1.VREG_EN
GND: C4.2, C5.2, C6.2, C7.2, C9.1, C10.1, C11.1, C12.1, C13.2, C14.2, C15.1, C16.-, C17.2, IC1.5 (GND), IC1.10 ((ADC9/INT0/T0)PB6), IC1.14 ((ADC5/AIN0)PA6), IC1.17 ((ADC3/ICP0)PA4), IC1.21 (GND), J1.6, J2.GND (GNDBREAK), J2.P$4 (GND), P1.6, Q4.P$3 (G), R7.1, R8.1, R9.1, R10.1, R11.1, R12.1, R14.1, S1.1 (0), S1.2 (0), U1.P$9 (THERMAL), U1.THERMAL, U1.THERMAL1 (THERMAL), U1.THERMAL2 (THERMAL), U1.THERMAL3 (THERMAL), U1.THERMAL4 (THERMAL), U1.THERMAL5 (THERMAL), U1.THERMAL6 (THERMAL), U1.THERMAL7 (THERMAL), U1.THERMAL8 (THERMAL), U1.THERMAL9 (THERMAL), U2.1 (GND), U$1.GND4 (GND), U$1.GND5 (GND), U$1.GND@28 (GND), U$1.GND@58 (GND), U$2.2 (GND), X1.2@1 (GND), X1.2@2 (GND), X1.2@3 (GND), X1.2@4 (GND), X1.2@5 (GND), X1.2@6 (GND)
GPWM: IC1.2 ((OC1B)PB3), R2.1, R9.2
GREENC: C2.2, L2.P$2 (2), U1.P$6
GSENSE: C5.1, IC1.13 ((ADC6/AIN1)PA7), R5.1
unnamed: U1.P$2, U1.P$5
unnamed: C8.1, U$1.ANT
unnamed: Q3.P$3 (G), R3.2
unnamed: Q2.P$3 (G), R2.2
unnamed: Q1.P$3 (G), R1.2
unnamed: Q1.P$4 (S), R4.2, R8.2
unnamed: D1.P$A (A), L1.P$1 (1), Q1.P$1 (D), Q1.P$2 (D), Q1.P$5 (D), Q1.P$6 (D)
unnamed: C12.2, IC1.22 ((AREF)PA3)
unnamed: J2.VIN0 (PWR), J2.VIN1 (PWR), Q4.P$1 (D), Q4.P$2 (D), Q4.P$5 (D), Q4.P$6 (D)
unnamed: C10.2, IC1.18 (AVCC), L4.2
unnamed: BLUE.C, R13.2
unnamed: C17.1, U$2.4 (BYPASS)
unnamed: D2.P$A (A), L2.P$1 (1), Q2.P$1 (D), Q2.P$2 (D), Q2.P$5 (D), Q2.P$6 (D)
unnamed: C7.1, C8.2, X1.1
unnamed: R13.1, U$1.LED(1)
unnamed: Q2.P$4 (S), R5.2, R10.2
unnamed: C16.+, R15.1
unnamed: C15.2, F1.2, U$2.1 (VIN), U$2.3 (ON/!OFF!)
unnamed: D3.P$A (A), L3.P$1 (1), Q3.P$1 (D), Q3.P$2 (D), Q3.P$5 (D), Q3.P$6 (D)
unnamed: Q3.P$4 (S), R6.2, R12.2
REDC: C1.2, L1.P$2 (2), U1.P$4
RESET: IC1.11 ((ADC10/!RESET!)PB7), J1.5
RPWM/MISO: IC1.31 ((MISO/DO/OC1A)PB1), J1.1, R1.1, R7.2
RSENSE: C4.1, IC1.15 ((ADC4/AIN2)PA5), R4.1
SPI_CLK: P1.4, U$1.CLK (SPI_CLK)
SPI_CSB: P1.3, U$1.CSB (SPI_CSB)
SPI_MISO: P1.5, U$1.MISO (SPI_MISO)
SPI_MOSI: P1.2, U$1.MOSI (SPI_MOSI)
SPI_RESET: P1.1, U$1.RESET (SPI_RESET)
V+: C1.1, C2.1, C3.1, D1.P$C (C), D2.P$C (C), D3.P$C (C), F1.1, Q4.P$4 (S), R15.2, U1.P$1, U1.P$3, U1.P$7
VCC: BLUE.A, C9.2, C11.2, C14.1, IC1.4 (VCC), J1.2, L4.1, U2.3 (VCC), U$1.VBATT, U$2.5 (VOUT)

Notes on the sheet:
firmware programming connector
pull-up reset to enable SPI
ambient light sensor
PIO(6)

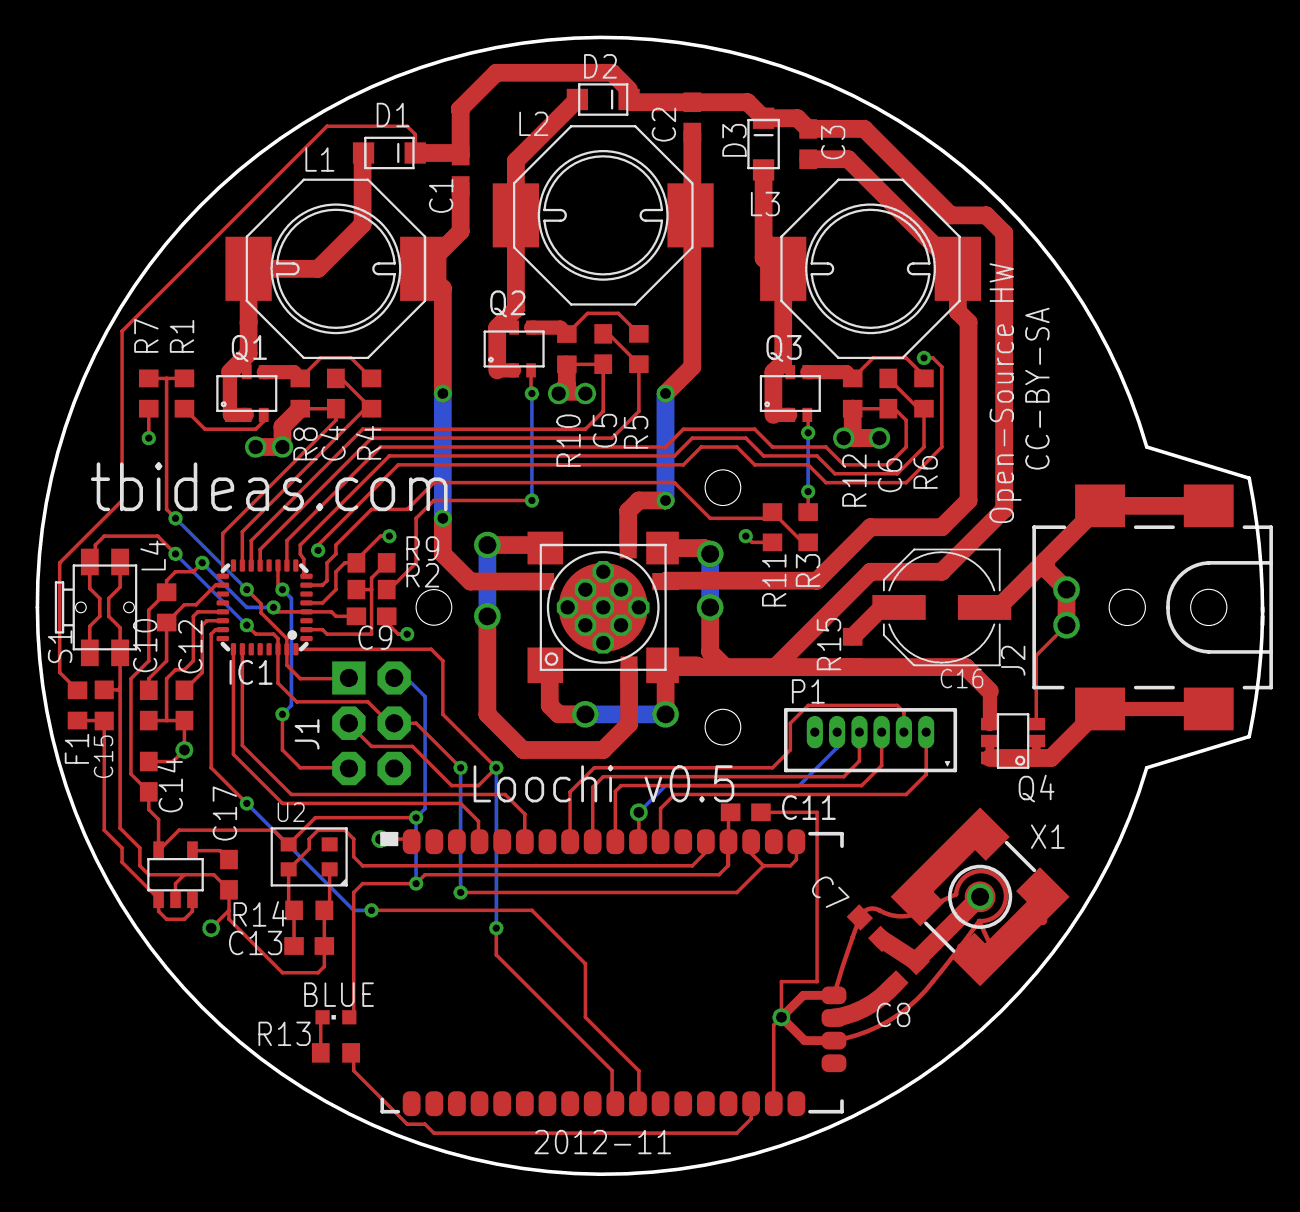
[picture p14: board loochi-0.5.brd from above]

Board: 2 copper layers, 68.8 x 63.8 mm, 55 parts (0 on the bottom side), 44 nets.

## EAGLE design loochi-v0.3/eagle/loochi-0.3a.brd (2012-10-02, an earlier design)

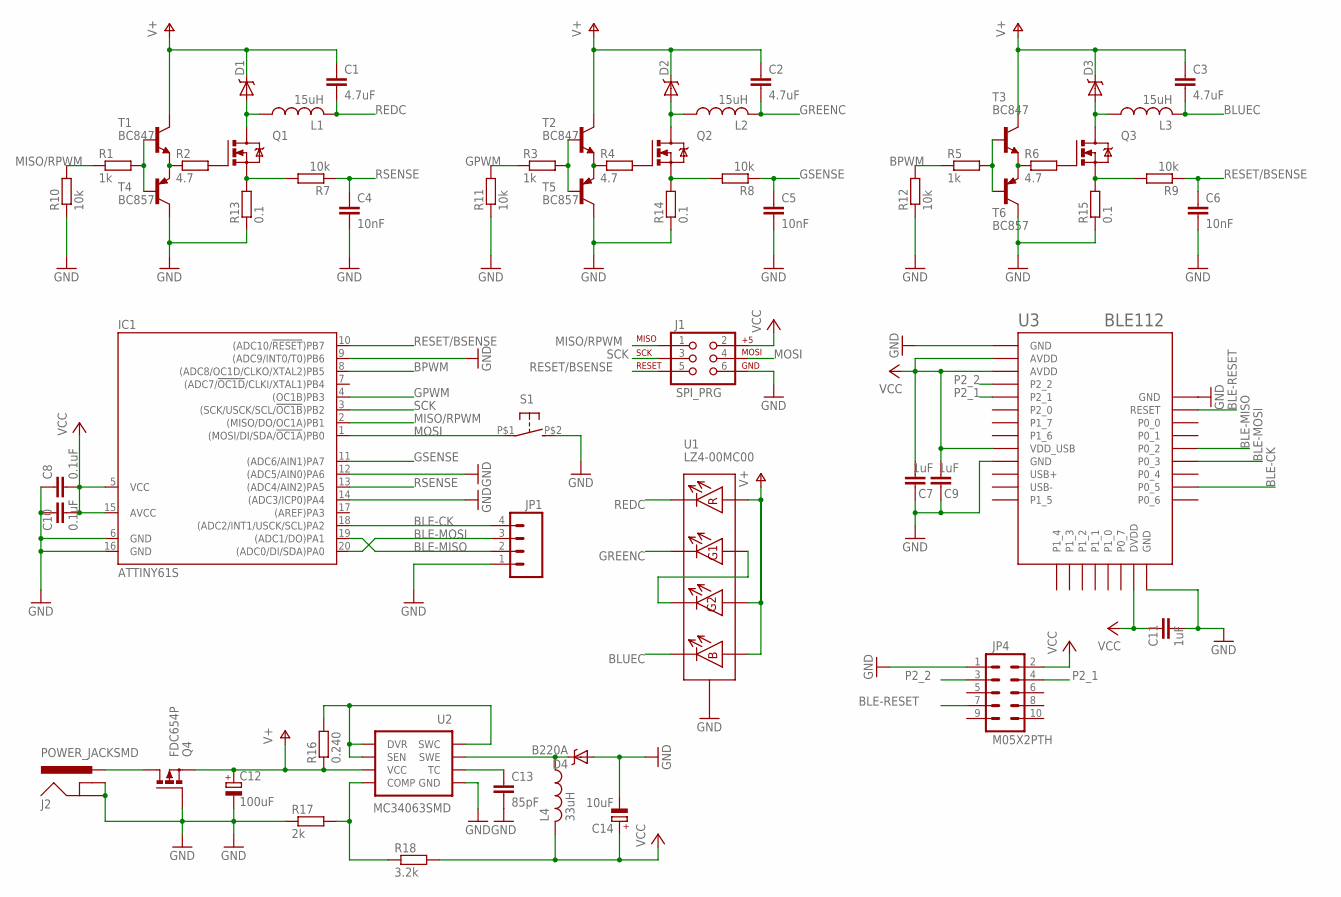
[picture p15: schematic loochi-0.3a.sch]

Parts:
C1, C2, C3: 4.7uF; C0805
C4, C5, C6: 10nF; C0805
C7, C9, C11: 1uF; C0805
C8, C10: 0.1uF; C0805
C12: 100uF; PANASONIC_D
C13: 85pF; C0805
C14: 10uF; UD-4X5,8_NICHICON
D1, D2, D3: PMEG4010CEH; SOD123F
D4: B220A; SMA-DIODE-BIG
IC1: ATTINY61S; SO20L
J1: SPI_PRG; 2X3-NS
J2: POWER_JACKSMD; POWER_JACK_SMD
JP1: M04PTH; 1X04
JP4: M05X2PTH; AVR_ICSP
L1, L2, L3: 15uH; BOURNS-6045
L4: 33uH; BOURNS-6045
Q1, Q2, Q3: PMN25ENSOT457; SOT457
Q4: FDC654P; SUPERSOT6
R1, R3, R5: 1k; R0805
R2, R4, R6: 4.7; R0805
R7, R8, R9, R10, R11, R12: 10k; R0805
R13, R14, R15: 0.1; R0805
R16: 0.240; R0805
R17: 2k; R0805
R18: 3.2k; R0805
S1: ALPS-SKRK39X29; ALPS-SKRK-39X29
T1, T2, T3: BC847; SOT23
T4, T5, T6: BC857; SOT23-BEC
U1: LZ4-00MC00
U2: MC34063SMD; SO08
U3: BLE112; SF-BLUEGIGA_BLE112-A

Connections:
BLE-CK: IC1.18 ((ADC2/INT1/USCK/SCL)PA2), JP1.4, U3.P0_5
BLE-MISO: IC1.19 ((ADC1/DO)PA1), JP1.2, U3.P0_2
BLE-MOSI: IC1.20 ((ADC0/DI/SDA)PA0), JP1.3, U3.P0_3
BLE-RESET: JP4.7, U3.RESET
BLUEC: C3.2, L3.P$2 (2), U1.P$8
BPWM: IC1.8 ((ADC8/OC1D/CLKO/XTAL2)PB5), R5.1, R12.2
GND: C4.2, C5.2, C6.2, C7.1, C8.1, C9.1, C10.1, C11.2, C12.-, C13.2, C14.-, D4.A, IC1.6 (GND), IC1.9 ((ADC9/INT0/T0)PB6), IC1.12 ((ADC5/AIN0)PA6), IC1.14 ((ADC3/ICP0)PA4), IC1.16 (GND), J1.6, J2.GND (GNDBREAK), J2.P$4 (GND), JP1.1, JP4.1, Q4.P$3 (G), R10.1, R11.1, R12.1, R13.1, R14.1, R15.1, R17.1, S1.P$2 (S), T4.C, T5.C, T6.C, U1.THERMAL, U1.THERMAL-VIA (THERMAL), U1.THERMAL-VIA2 (THERMAL), U2.4 (GND), U3.GND1 (GND), U3.GND2 (GND), U3.GND3 (GND), U3.GND4 (GND)
GPWM: IC1.4 ((OC1B)PB3), R3.1, R11.2
GREENC: C2.2, L2.P$2 (2), U1.P$6
GSENSE: C5.1, IC1.11 ((ADC6/AIN1)PA7), R8.1
MISO/RPWM: IC1.2 ((MISO/DO/OC1A)PB1), J1.1, R1.1, R10.2
MOSI: IC1.1 ((MOSI/DI/SDA/!OC1A!)PB0), J1.4, S1.P$1
unnamed: U1.P$1, U1.P$5
unnamed: R2.1, T1.2 (E), T4.E
unnamed: R1.2, T1.1 (B), T4.B
unnamed: Q1.P$3 (G), R2.2
unnamed: Q1.P$4 (S), R7.2, R13.2
unnamed: D1.P$A (A), L1.P$1 (1), Q1.P$1 (D), Q1.P$2 (D), Q1.P$5 (D), Q1.P$6 (D)
unnamed: R4.1, T2.2 (E), T5.E
unnamed: J2.VIN0 (PWR), J2.VIN1 (PWR), Q4.P$1 (D), Q4.P$2 (D), Q4.P$5 (D), Q4.P$6 (D)
unnamed: R3.2, T2.1 (B), T5.B
unnamed: Q2.P$3 (G), R4.2
unnamed: D2.P$A (A), L2.P$1 (1), Q2.P$1 (D), Q2.P$2 (D), Q2.P$5 (D), Q2.P$6 (D)
unnamed: R16.2, U2.1 (SWC), U2.7 (SEN), U2.8 (DVR)
unnamed: Q2.P$4 (S), R8.2, R14.2
unnamed: C13.1, U2.3 (TC)
unnamed: R6.1, T3.2 (E), T6.E
unnamed: R5.2, T3.1 (B), T6.B
unnamed: Q3.P$3 (G), R6.2
unnamed: D3.P$A (A), L3.P$1 (1), Q3.P$1 (D), Q3.P$2 (D), Q3.P$5 (D), Q3.P$6 (D)
unnamed: D4.C, L4.P$1 (1), U2.2 (SWE)
unnamed: Q3.P$4 (S), R9.2, R15.2
unnamed: R17.2, R18.1, U2.5 (COMP)
P2_1: JP4.4, U3.P2_1
P2_2: JP4.3, U3.P2_2
REDC: C1.2, L1.P$2 (2), U1.P$4
RESET/BSENSE: C6.1, IC1.10 ((ADC10/!RESET!)PB7), J1.5, R9.1
RSENSE: C4.1, IC1.13 ((ADC4/AIN2)PA5), R7.1
SCK: IC1.3 ((SCK/USCK/SCL/!OC1B!)PB2), J1.3
V+: C1.1, C2.1, C3.1, C12.+, D1.P$C (C), D2.P$C (C), D3.P$C (C), Q4.P$4 (S), R16.1, T1.3 (C), T2.3 (C), T3.3 (C), U1.P$2, U1.P$3, U1.P$7, U2.6 (VCC)
VCC: C7.2, C8.2, C9.2, C10.2, C11.1, C14.+, IC1.5 (VCC), IC1.15 (AVCC), J1.2, JP4.2, L4.P$2 (2), R18.2, U3.AVDD1 (AVDD), U3.AVDD2 (AVDD), U3.DVDD, U3.VDD_USB

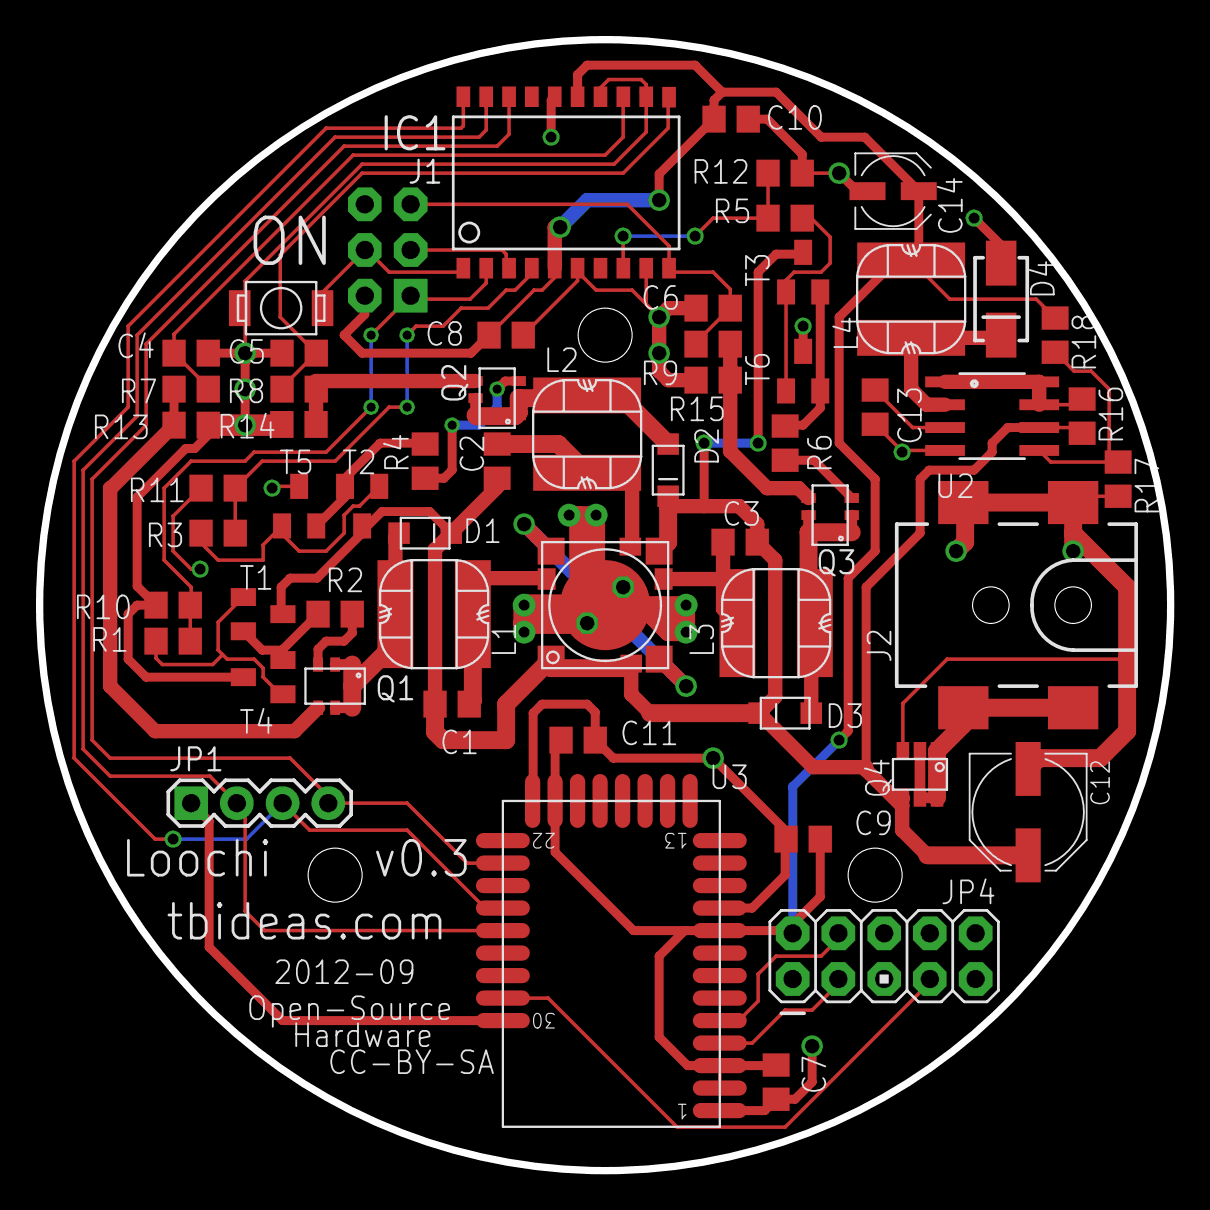
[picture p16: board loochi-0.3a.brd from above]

Board: 2 copper layers, 62.8 x 62.8 mm, 59 parts (0 on the bottom side), 41 nets.

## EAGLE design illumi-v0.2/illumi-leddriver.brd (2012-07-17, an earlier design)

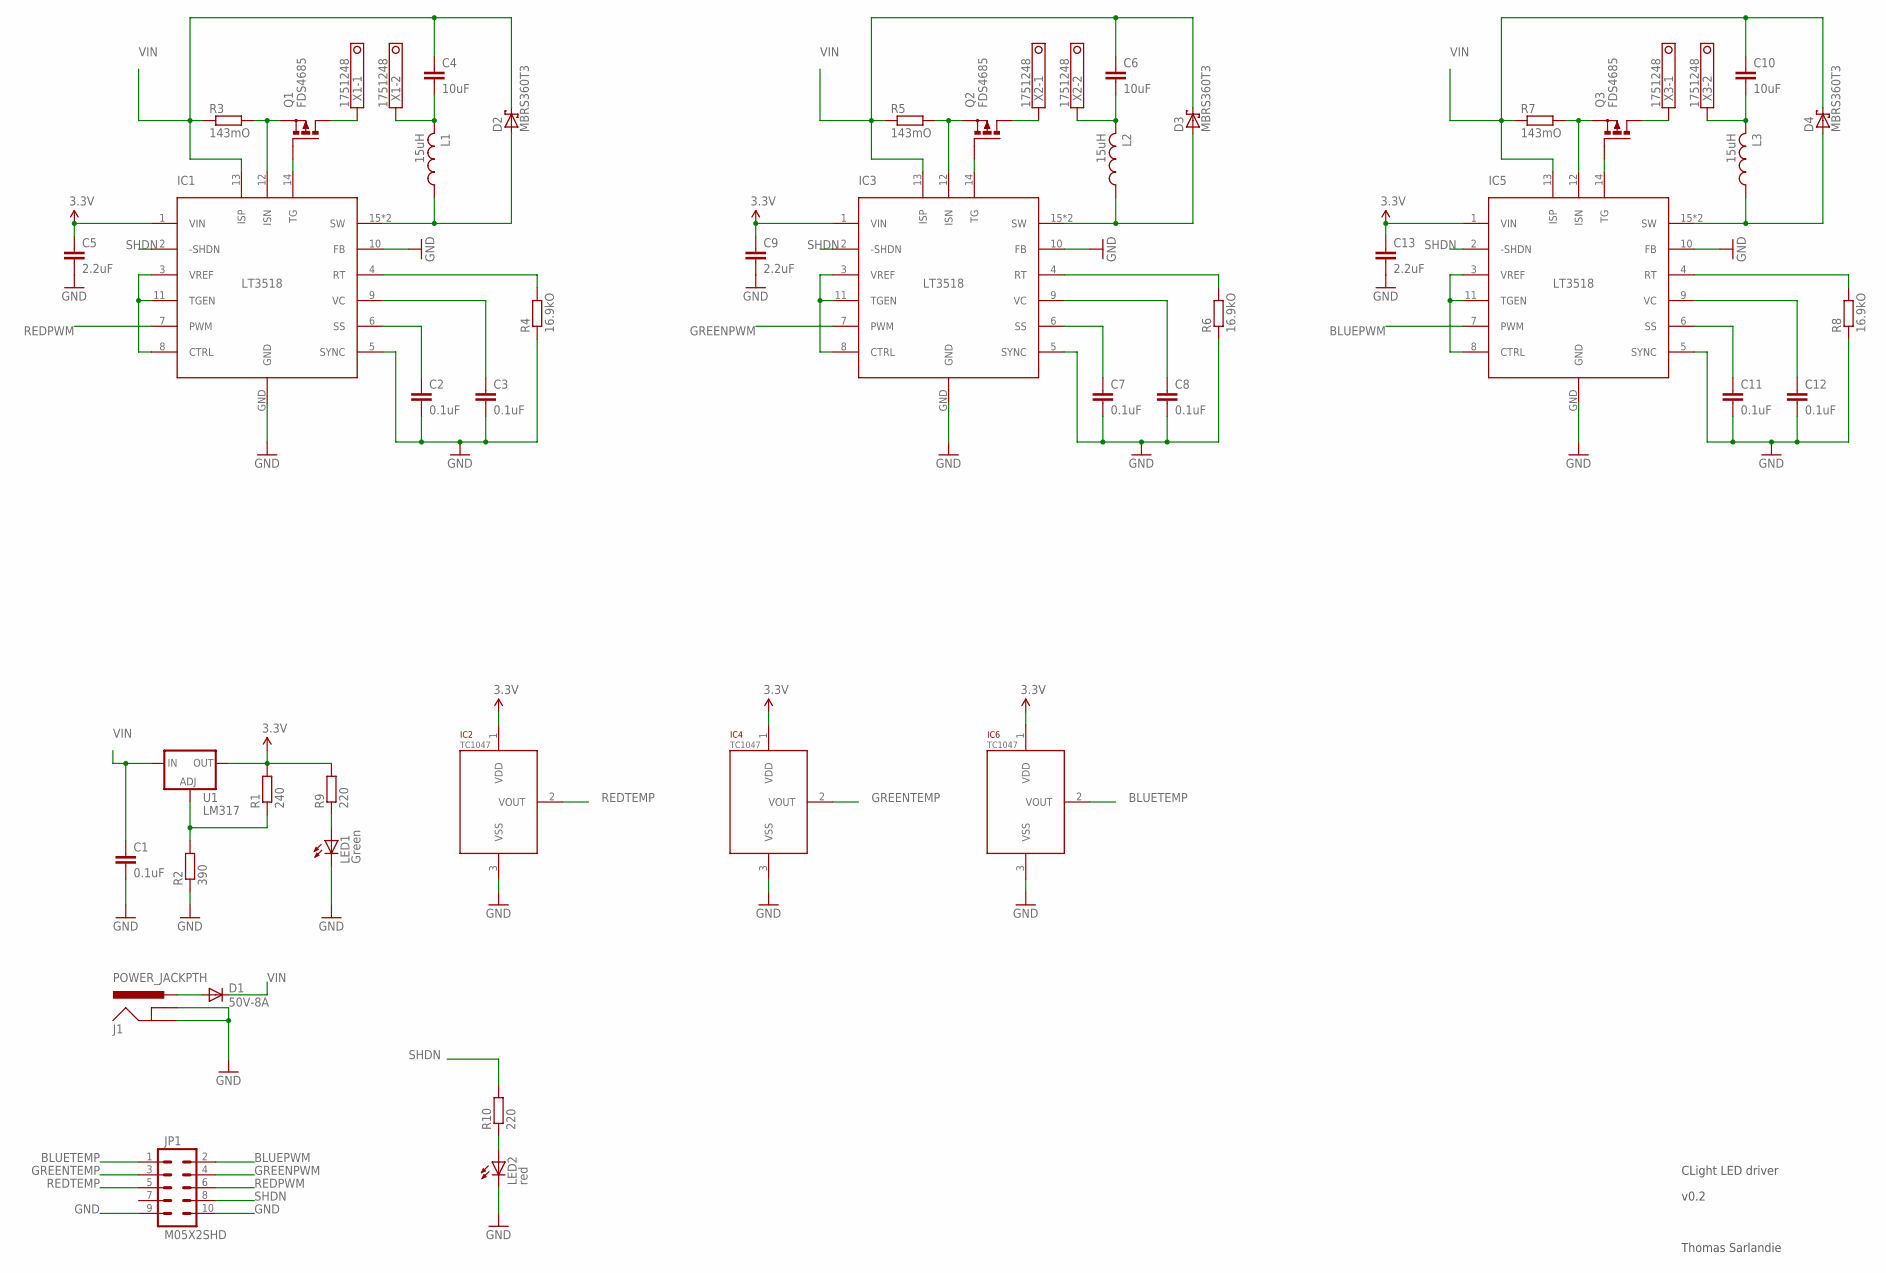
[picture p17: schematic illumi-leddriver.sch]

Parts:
C1, C2, C3, C7, C8, C11, C12: 0.1uF; C1206
C4, C6, C10: 10uF; C1206
C5, C9, C13: 2.2uF; C1206
D1: 50V-8A; SMC
D2, D3, D4: MBRS360T3; SMC
IC1, IC3, IC5: LT3518TSSOP16-EXPOSED-PAD-LARGE; TSSOP16-EXPOSED_PAD_LARGE
IC2, IC4, IC6: TC1047; SOT-23B
J1: POWER_JACKPTH; POWER_JACK_PTH
JP1: M05X2SHD; 2X5-SHROUDED
L1, L2, L3: 15uH; L2020
LED1: Green; LED-1206
LED2: red; LED-1206
Q1, Q2, Q3: FDS4685; SO-08
R1: 240; R1206
R2: 390; R1206
R3, R5, R7: 143mO; R1206
R4, R6, R8: 16.9kO; R1206
R9, R10: 220; R1206
U1: LM317; SOT223
X1, X2, X3: 1751248

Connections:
3.3V: C5.1, C9.1, C13.1, IC1.1 (VIN), IC2.1 (VDD), IC3.1 (VIN), IC4.1 (VDD), IC5.1 (VIN), IC6.1 (VDD), R1.2, R9.2, U1.2 (OUT)
BLUEPWM: IC5.7 (PWM), JP1.2
BLUETEMP: IC6.2 (VOUT), JP1.1
GND: C1.2, C2.2, C3.2, C5.2, C7.2, C8.2, C9.2, C11.2, C12.2, C13.2, IC1.5 (SYNC), IC1.10 (FB), IC1.GND, IC2.3 (VSS), IC3.5 (SYNC), IC3.10 (FB), IC3.GND, IC4.3 (VSS), IC5.5 (SYNC), IC5.10 (FB), IC5.GND, IC6.3 (VSS), J1.GND, J1.GNDBREAK, JP1.9, JP1.10, LED1.C, LED2.C, R2.1, R4.1, R6.1, R8.1
GREENPWM: IC3.7 (PWM), JP1.4
GREENTEMP: IC4.2 (VOUT), JP1.3
unnamed: IC1.3 (VREF), IC1.8 (CTRL), IC1.11 (TGEN)
unnamed: IC3.3 (VREF), IC3.8 (CTRL), IC3.11 (TGEN)
unnamed: R1.1, R2.2, U1.1 (ADJ)
unnamed: IC3.12 (ISN), Q2.1 (S), Q2.2 (S), Q2.3 (S), R5.2
unnamed: IC1.12 (ISN), Q1.1 (S), Q1.2 (S), Q1.3 (S), R3.2
unnamed: IC1.14 (TG), Q1.4 (G)
unnamed: Q1.5 (D), Q1.6 (D), Q1.7 (D), Q1.8 (D), X1.1
unnamed: C4.2, L1.P$2 (2), X1.2
unnamed: D2.A, IC1.15 (SW), IC1.16 (SW), L1.P$1 (1)
unnamed: IC3.14 (TG), Q2.4 (G)
unnamed: IC1.4 (RT), R4.2
unnamed: Q2.5 (D), Q2.6 (D), Q2.7 (D), Q2.8 (D), X2.1
unnamed: C6.2, L2.P$2 (2), X2.2
unnamed: D3.A, IC3.15 (SW), IC3.16 (SW), L2.P$1 (1)
unnamed: C2.1, IC1.6 (SS)
unnamed: C3.1, IC1.9 (VC)
unnamed: IC3.4 (RT), R6.2
unnamed: C7.1, IC3.6 (SS)
unnamed: C8.1, IC3.9 (VC)
unnamed: IC5.3 (VREF), IC5.8 (CTRL), IC5.11 (TGEN)
unnamed: IC5.12 (ISN), Q3.1 (S), Q3.2 (S), Q3.3 (S), R7.2
unnamed: IC5.14 (TG), Q3.4 (G)
unnamed: Q3.5 (D), Q3.6 (D), Q3.7 (D), Q3.8 (D), X3.1
unnamed: C10.2, L3.P$2 (2), X3.2
unnamed: D4.A, IC5.15 (SW), IC5.16 (SW), L3.P$1 (1)
unnamed: IC5.4 (RT), R8.2
unnamed: C11.1, IC5.6 (SS)
unnamed: C12.1, IC5.9 (VC)
unnamed: D1.A, J1.PWR
unnamed: LED1.A, R9.1
unnamed: LED2.A, R10.1
REDPWM: IC1.7 (PWM), JP1.6
REDTEMP: IC2.2 (VOUT), JP1.5
SHDN: IC1.2 (-SHDN), IC3.2 (-SHDN), IC5.2 (-SHDN), JP1.8, R10.2
VIN: C1.1, C4.1, C6.1, C10.1, D1.C, D2.C, D3.C, D4.C, IC1.13 (ISP), IC3.13 (ISP), IC5.13 (ISP), R3.1, R5.1, R7.1, U1.3 (IN)

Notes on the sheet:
CLight LED driver
v0.2
Thomas Sarlandie

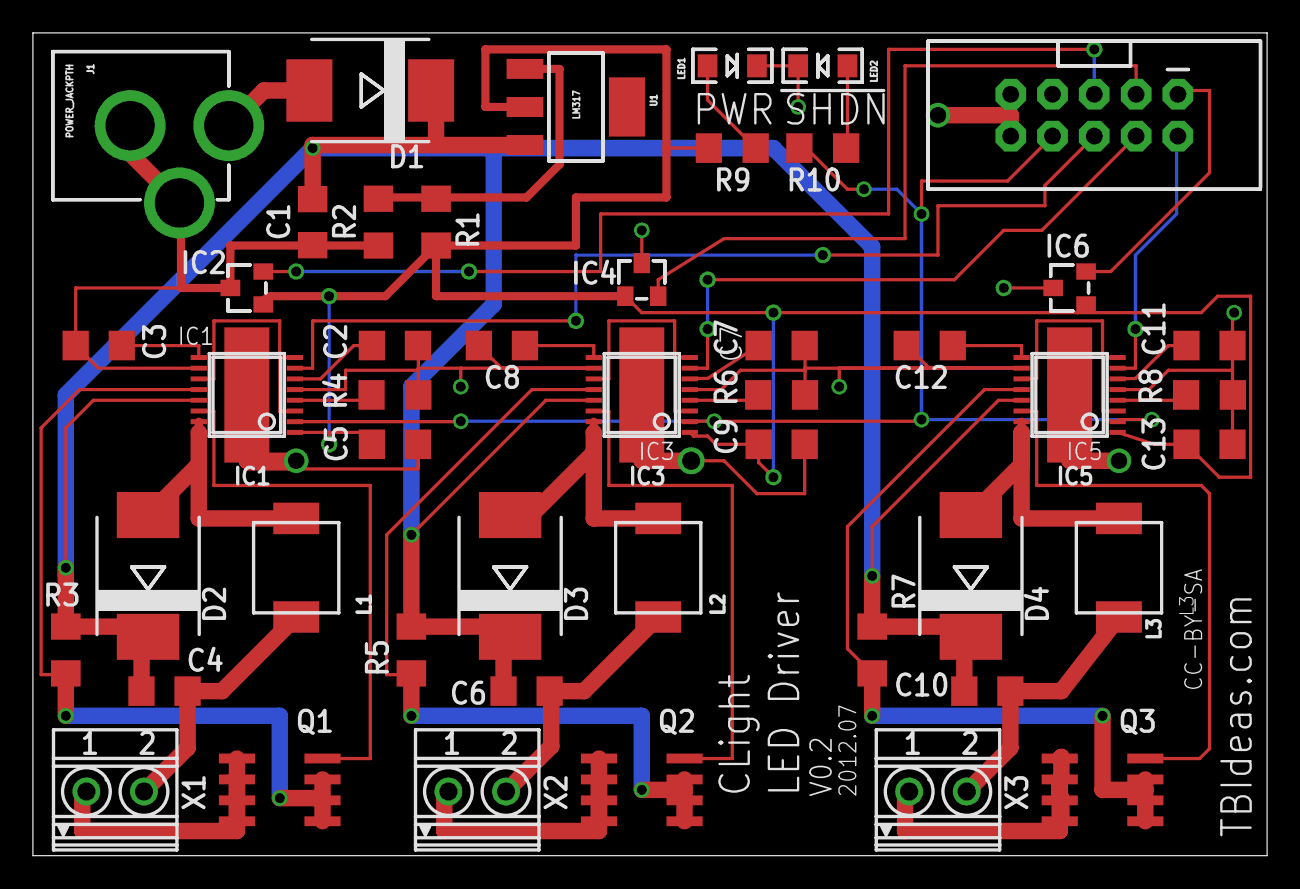
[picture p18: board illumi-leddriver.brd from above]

Board: 2 copper layers, 75.0 x 50.0 mm, 47 parts (0 on the bottom side), 41 nets.

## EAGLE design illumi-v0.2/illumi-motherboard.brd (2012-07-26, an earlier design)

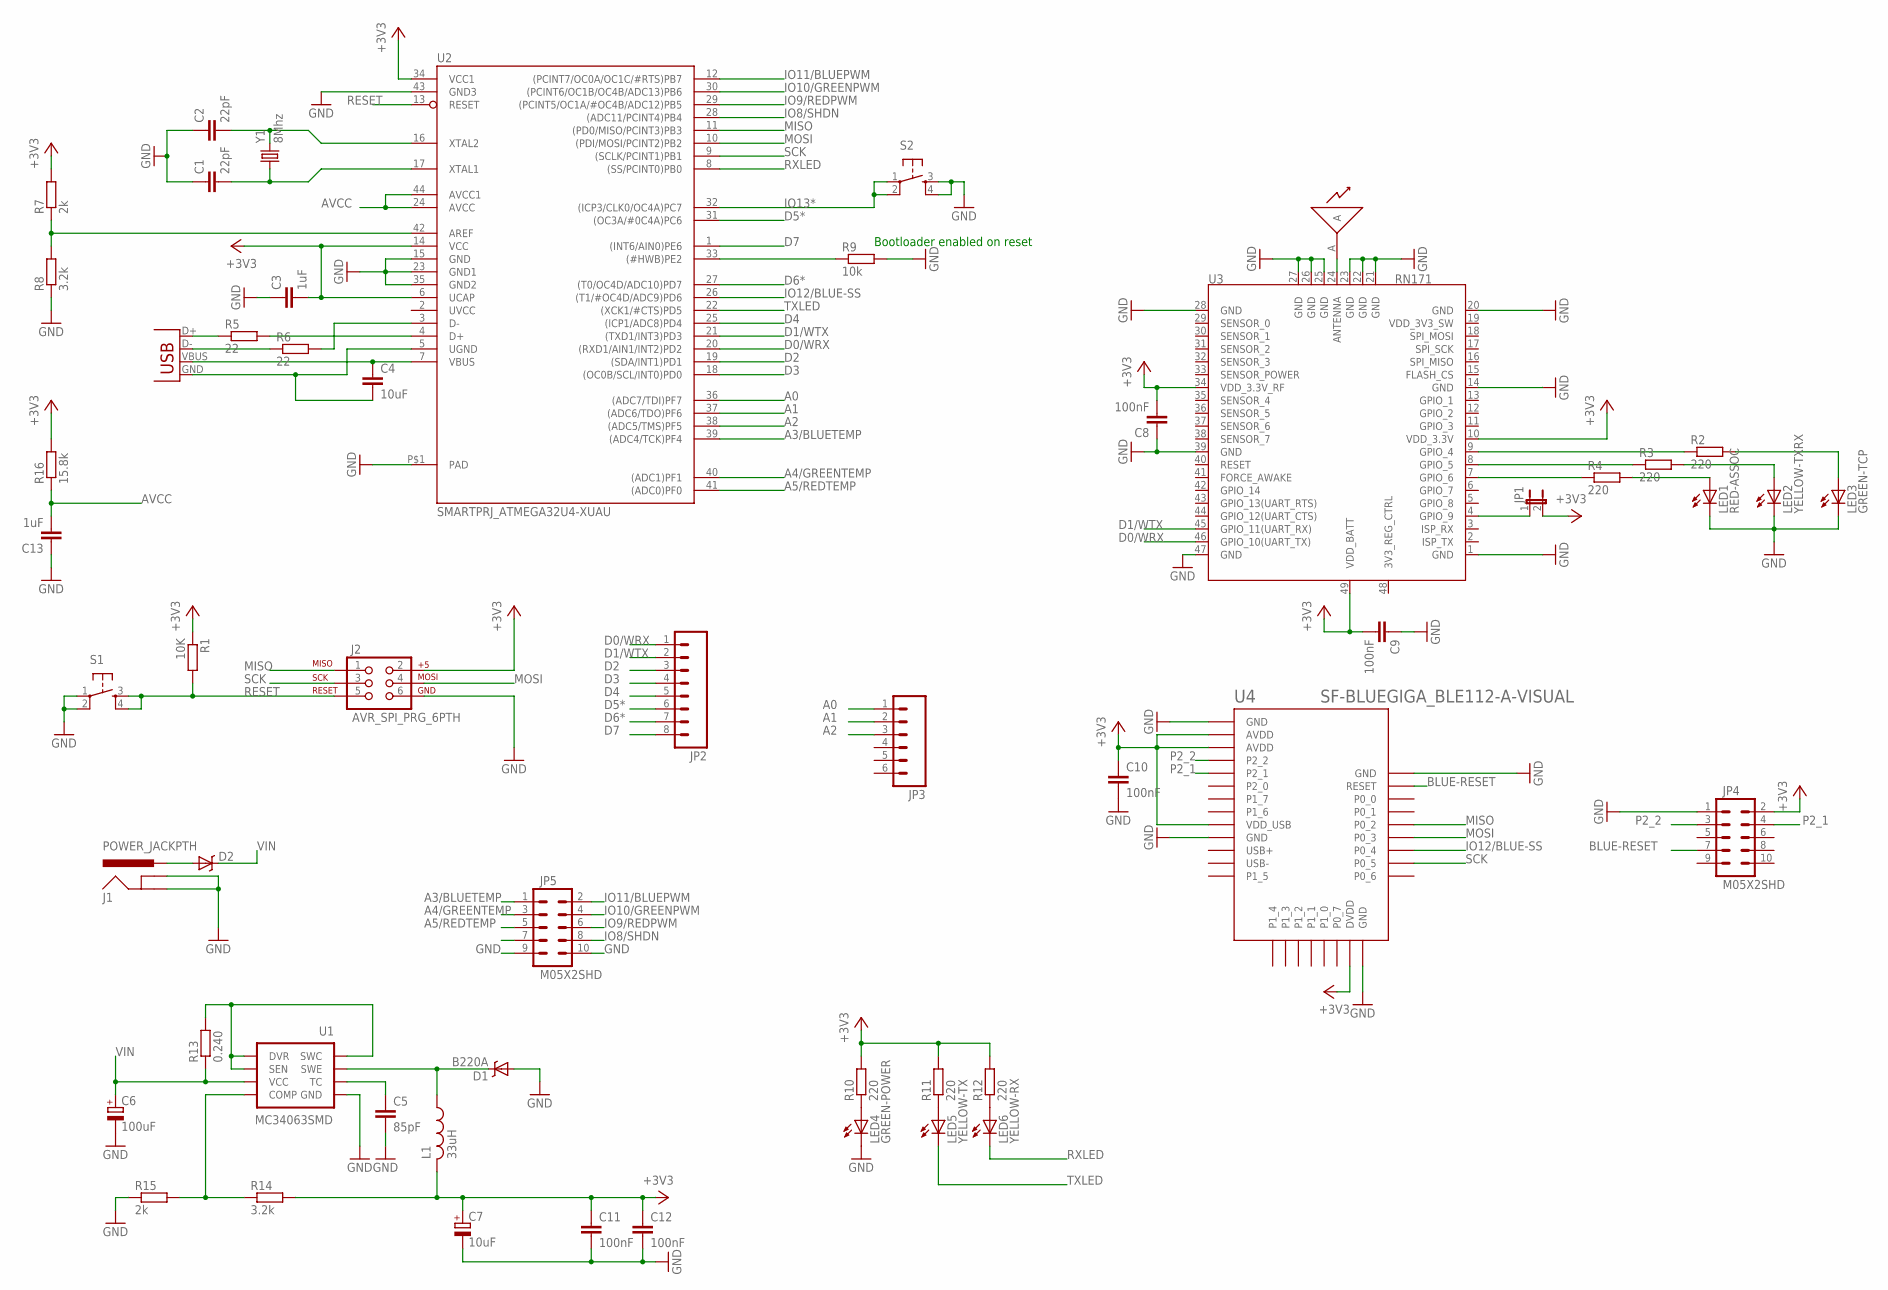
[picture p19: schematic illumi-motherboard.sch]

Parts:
A1: ANTENNAWIRE; ANTENNA-WIRE
C1, C2: 22pF; C0805
C3, C13: 1uF; C0805
C4: 10uF; C0805
C5: 85pF; C0805
C6: 100uF; PANASONIC_D
C7: 10uF; SMC_C
C8, C9, C10, C11, C12: 100nF; C0805
D1: B220A; SMA-DIODE-BIG
D2: DIODE-SCHOTTKYBIGPAD; SMA-DIODE-BIG
J1: POWER_JACKPTH; POWER_JACK_PTH
J2: AVR_SPI_PRG_6PTH; 2X3
JP1: JUMPER-2PTH; 1X02
JP2: M081X08; 1X08
JP3: M06FEMALE_LOCK; 1X06_FEMALE_LOCK.010
JP4, JP5: M05X2SHD; 2X5-SHROUDED
L1: 33uH; BOURNS-6045
LED1: RED-ASSOC; SML0805
LED2: YELLOW-TXRX; SML0805
LED3: GREEN-TCP; SML0805
LED4: GREEN-POWER; SML0805
LED5: YELLOW-TX; SML0805
LED6: YELLOW-RX; SML0805
R1: 10K; R0805
R2, R3, R4, R10, R11, R12: 220; R0805
R5, R6: 22; R0805
R7, R15: 2k; R0805
R8, R14: 3.2k; R0805
R9: 10k; R0805
R13: 0.240; R1206
R16: 15.8k; R0805
S1, S2: TAC_SWITCHB3FS; OMRON-B3FS
U1: MC34063SMD; SO08
U2: SMARTPRJ_ATMEGA32U4-XUAU; SMARTPRJ_TQFP44-PAD
U3: RN171; MODULE_49P-1.27-26.67X17.78
U4: SF-BLUEGIGA_BLE112-A-VISUAL; SF-BLUEGIGA_BLE112-A
X1: USB-MICROB
Y1: 8Mhz; HC49US

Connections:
+3V3: C3.2, C7.+, C8.2, C9.2, C10.1, C11.1, C12.1, J2.2, JP1.2, JP4.2, L1.P$2 (2), R1.1, R7.2, R10.2, R11.2, R12.2, R14.2, R16.2, U2.6 (UCAP), U2.14 (VCC), U2.34 (VCC1), U3.10 (VDD_3.3V), U3.34 (VDD_3.3V_RF), U3.49 (VDD_BATT), U4.AVDD1 (AVDD), U4.AVDD2 (AVDD), U4.DVDD, U4.VDD_USB
A0: JP3.1, U2.36 ((ADC7/TDI)PF7)
A1: JP3.2, U2.37 ((ADC6/TDO)PF6)
A2: JP3.3, U2.38 ((ADC5/TMS)PF5)
A3/BLUETEMP: JP5.1, U2.39 ((ADC4/TCK)PF4)
A4/GREENTEMP: JP5.3, U2.40 ((ADC1)PF1)
A5/REDTEMP: JP5.5, U2.41 ((ADC0)PF0)
AVCC: C13.2, R16.1, U2.24 (AVCC), U2.44 (AVCC1)
BLUE-RESET: JP4.7, U4.RESET
D0/WRX: JP2.1, U2.20 ((RXD1/AIN1/INT2)PD2), U3.46 (GPIO_10(UART_TX))
D1/WTX: JP2.2, U2.21 ((TXD1/INT3)PD3), U3.45 (GPIO_11(UART_RX))
D2: JP2.3, U2.19 ((SDA/INT1)PD1)
D3: JP2.4, U2.18 ((OC0B/SCL/INT0)PD0)
D4: JP2.5, U2.25 ((ICP1/ADC8)PD4)
D5*: JP2.6, U2.31 ((OC3A/#0C4A)PC6)
D6*: JP2.7, U2.27 ((T0/OC4D/ADC10)PD7)
D7: JP2.8, U2.1 ((INT6/AIN0)PE6)
GND: C1.1, C2.1, C3.1, C5.2, C6.-, C7.-, C8.1, C9.1, C10.2, C11.2, C12.2, C13.1, D1.A, J1.GND, J1.GNDBREAK, J2.6, JP4.1, JP5.9, JP5.10, LED1.C, LED2.C, LED3.C, LED4.C, R8.1, R9.2, R15.1, S1.1, S1.2, S2.3, S2.4, U1.4 (GND), U2.15 (GND), U2.23 (GND1), U2.35 (GND2), U2.43 (GND3), U2.P$1 (PAD), U3.1 (GND), U3.14 (GND), U3.20 (GND), U3.21 (GND), U3.22 (GND), U3.23 (GND), U3.25 (GND), U3.26 (GND), U3.27 (GND), U3.28 (GND), U3.39 (GND), U3.47 (GND), U4.GND1 (GND), U4.GND2 (GND), U4.GND3 (GND), U4.GND4 (GND)
IO8/SHDN: JP5.8, U2.28 ((ADC11/PCINT4)PB4)
IO9/REDPWM: JP5.6, U2.29 ((PCINT5/OC1A/#OC4B/ADC12)PB5)
IO10/GREENPWM: JP5.4, U2.30 ((PCINT6/OC1B/OC4B/ADC13)PB6)
IO11/BLUEPWM: JP5.2, U2.12 ((PCINT7/OC0A/OC1C/#RTS)PB7)
IO12/BLUE-SS: U2.26 ((T1/#OC4D/ADC9)PD6), U4.P0_4
IO13*: S2.1, S2.2, U2.32 ((ICP3/CLK0/OC4A)PC7)
MISO: J2.1, U2.11 ((PD0/MISO/PCINT3)PB3), U4.P0_2
MOSI: J2.4, U2.10 ((PDI/MOSI/PCINT2)PB2), U4.P0_3
unnamed: LED4.A, R10.1
unnamed: A1.A, U3.24 (ANTENNA)
unnamed: R2.1, U3.9 (GPIO_4)
unnamed: R3.1, U3.8 (GPIO_5)
unnamed: R4.1, U3.7 (GPIO_6)
unnamed: LED1.A, R4.2
unnamed: LED2.A, R3.2
unnamed: LED3.A, R2.2
unnamed: C4.2, U2.5 (UGND), X1.GND
unnamed: R5.1, X1.D+
unnamed: JP1.1, U3.4 (GPIO_9)
unnamed: R6.1, X1.D-
unnamed: C4.1, U2.7 (VBUS), X1.VBUS
unnamed: R5.2, U2.4 (D+)
unnamed: R6.2, U2.3 (D-)
unnamed: R7.1, R8.2, U2.42 (AREF)
unnamed: LED5.A, R11.1
unnamed: LED6.A, R12.1
unnamed: R9.1, U2.33 ((#HWB)PE2)
unnamed: R13.2, U1.1 (SWC), U1.7 (SEN), U1.8 (DVR)
unnamed: D1.C, L1.P$1 (1), U1.2 (SWE)
unnamed: C5.1, U1.3 (TC)
unnamed: R14.1, R15.2, U1.5 (COMP)
unnamed: D2.A, J1.PWR
P2_1: JP4.4, U4.P2_1
P2_2: JP4.3, U4.P2_2
RESET: J2.5, R1.2, S1.3, S1.4, U2.13 (RESET)
RXLED: LED6.C, U2.8 ((SS/PCINT0)PB0)
SCK: J2.3, U2.9 ((SCLK/PCINT1)PB1), U4.P0_5
TXLED: LED5.C, U2.22 ((XCK1/#CTS)PD5)
UVCC: U2.2 (UVCC)
VIN: C6.+, D2.C, R13.1, U1.6 (VCC)
XTAL1: C1.2, U2.17 (XTAL1), Y1.1
XTAL2: C2.2, U2.16 (XTAL2), Y1.2

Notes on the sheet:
Bootloader enabled on reset

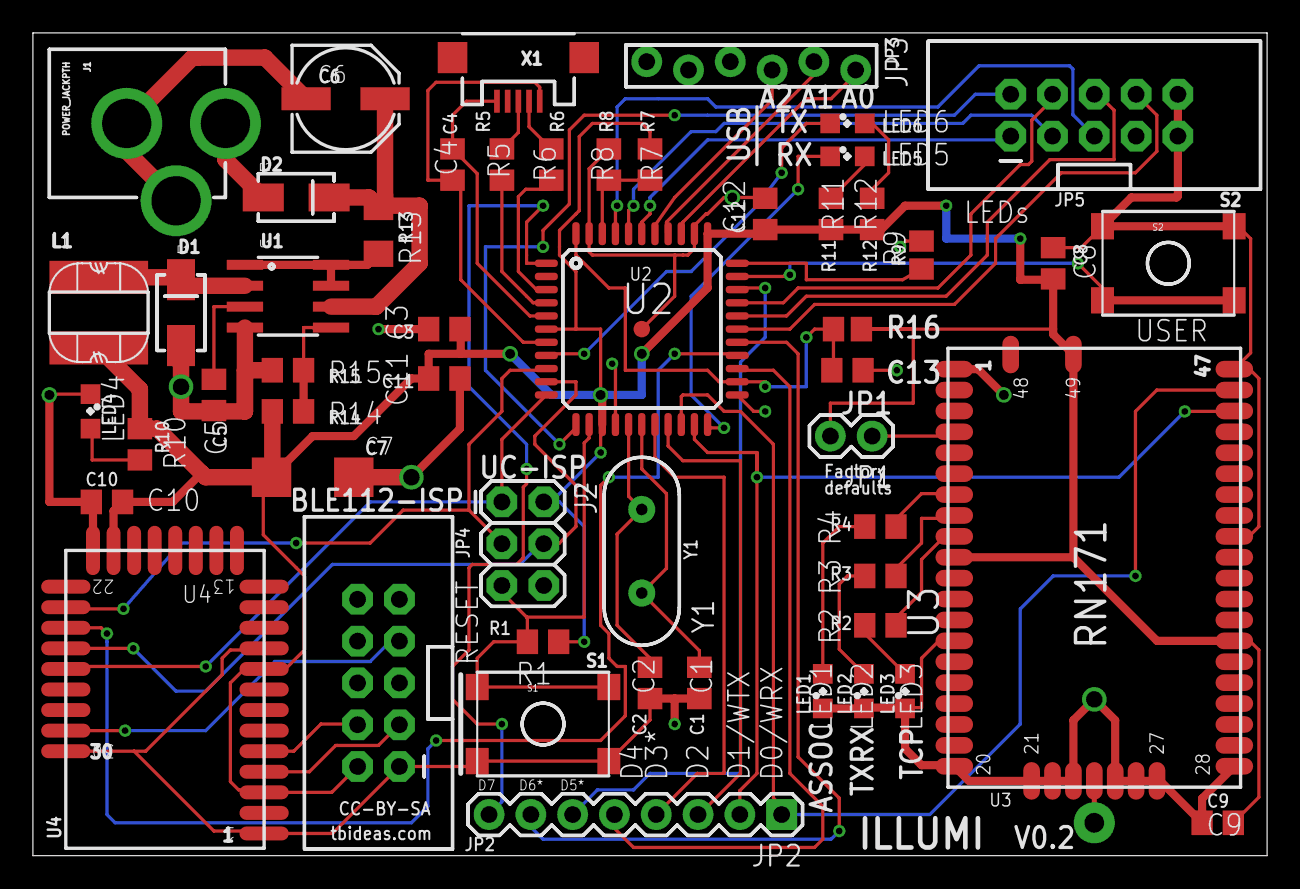
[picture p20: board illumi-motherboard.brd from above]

Board: 2 copper layers, 75.0 x 50.0 mm, 54 parts (0 on the bottom side), 59 nets.

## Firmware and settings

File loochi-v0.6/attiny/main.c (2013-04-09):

#include <util/delay.h>
#include <avr/interrupt.h>
#include "globals.h"
#include "adc.h"
#include "brightness.h"
#include "current.h"
#include "serial.h"

#define LOOP_DELAY 100

void init_timer0(void);

/* 
 * Interrupt vectors
 * (sorted by priority) 
 */

// Pin change interrupt (CS changed)
ISR(SIG_PIN_CHANGE)
{
  serial_cs(PINB & (1 << PB2));
}

// Timer0 overflow - Every 32us
ISR(SIG_OVERFLOW0)
{
	brightness_pwm_loop();
	adc_loop();
}

// Serial buffer overflow (1 byte received)
ISR(SIG_USI_OVERFLOW)
{
	serial_rx_byte(USIDR);
	
	// Clear the interrupt
	USISR = (1 << USIOIF);
}

// ADC reading ready
ISR(SIG_ADC)
{
	/* Note: it's important to read ADCL first and then ADCH */
	uint16_t adc = ADCL;
	adc |= ADCH << 8;

	process_adc_reading(adc);
}

int main(void)
{
	/* Use the hardware (Timer1) to generate a fast (250kHz) pwm
	 * that will drive the buck converter on/off.
	 * 
	 * Initialize the PWM value *before*.
	 */
	redcpwm = 0x00;
	greencpwm = 0x00;
	bluecpwm= 0xFF; /* inverted */
	init_current_loop();
	
	/* Initializes the ADC */
	init_adc();
	
	/* Run a much slower (122Hz) PWM (based on Timer0 interrupts) */
	init_timer0();
	
	/* Initializes the serial port and prepare to receive data */
	init_serial();

	/* Initialize global variables */
	pwm_c = 0x00;
	pwm_red =   0x000;
	pwm_green = 0x000;
	pwm_blue =  0x000;

	/* Enable pull-up on PB0 */
	PORTB |= (1 << PB0);

	/* Enable interrupts and let the show begin! */
	sei();

	while(1) {
		_delay_ms(10);
		// If button pressed
		if ((PINB & (1 << PB0)) == 0) {
			if (pwm_red == 0 && pwm_green == 0 && pwm_blue == 0) {
				pwm_red = pwm_green = pwm_blue = 0xFF;
				
				_delay_ms(30);
			}
			else {
				pwm_red = pwm_green = pwm_blue = 0;
				_delay_ms(30);
			}
		}
	}
}

/*
 * Timer0 is used to generate software interrupts that we use for different purpose.
 * 
 * This counter counts @8Mhz and will overflow every 256 ticks so the interrupt will be
 * called every: t = 1/8Mhz * 256 = 32uS
 */
void init_timer0()
{
	/* Enable counter with no prescaling (speed will be 8Mhz) */
	TCCR0B = (1 << CS00);
	
	/* Enable interrupt when an overflow occurs */
	TIMSK |= (1 << TOIE0);
}

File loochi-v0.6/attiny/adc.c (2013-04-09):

#include <avr/io.h>
#include <avr/pgmspace.h>
#include "globals.h"
#include "adc.h"

/* ADC configuration for each sense resistor */
#define ADMUX_RED    	((1 << REFS1) | 0x12)
#define ADMUX_GREEN  	((1 << REFS1) | 0x17)
#define ADMUX_BLUE   	((1 << REFS1) | 0x19)
uint8_t adc_discard;

/*
 * Truthtable to choose which channel the ADC should read next.
 * Input: 6bits
 *  00XXXXXX
 *    ++     -> previous selected channel (00=red, 01=green, 10=blue)
 *      +    -> have we got a valid reading on this channel already
 *       +   -> is red on
 *        +  -> is green on
 *         + -> is blue on
 * Output: next value of ADMUX or 0 if no new ADC is to be chosen
 */
PROGMEM uint8_t ADC_TRUTHTABLE[] = {
	0,ADMUX_BLUE,ADMUX_GREEN,ADMUX_GREEN,ADMUX_RED,ADMUX_RED,ADMUX_RED,ADMUX_RED,0,ADMUX_BLUE,ADMUX_GREEN,ADMUX_GREEN,ADMUX_RED,
	ADMUX_BLUE,ADMUX_GREEN,ADMUX_GREEN,0,ADMUX_BLUE,ADMUX_GREEN,ADMUX_GREEN,ADMUX_RED,ADMUX_BLUE,ADMUX_GREEN,ADMUX_GREEN,0,
	ADMUX_BLUE,ADMUX_GREEN,ADMUX_BLUE,ADMUX_RED,ADMUX_BLUE,ADMUX_RED,ADMUX_BLUE,0,ADMUX_BLUE,ADMUX_GREEN,ADMUX_BLUE,ADMUX_RED,
	ADMUX_BLUE,ADMUX_RED,ADMUX_BLUE,0,ADMUX_BLUE,ADMUX_GREEN,ADMUX_GREEN,ADMUX_RED,ADMUX_RED,ADMUX_RED,ADMUX_RED
};

/* Expected reading of the ADC for a given value of Ton to get 700mA on the LED
 *
 * The formula is: ADC = 2*Ton/Tperiod*Iled*1024/2.56
 * Everything is known except Ton.
 * $ perl -e 'print join(",", map { sprintf "%.0f", (2*$_/0xff*0.7*1024/2.56)} 0..255)'
 * (the first value was manually hacked to -1 to make sure the thing starts)
 */
PROGMEM int16_t ADC_TARGET_VALUES[] = {
	-1,2,4,7,9,11,13,15,18,20,22,24,26,29,31,33,35,37,40,42,44,46,48,51,53,55,57,59,61,64,66,68,70,72,75,77,79,81,83,86,88,90,92,94,97,99,101,103,105,
	108,110,112,114,116,119,121,123,125,127,130,132,134,136,138,141,143,145,147,149,152,154,156,158,160,163,165,167,169,171,173,176,178,180,182,184,
	187,189,191,193,195,198,200,202,204,206,209,211,213,215,217,220,222,224,226,228,231,233,235,237,239,242,244,246,248,250,253,255,257,259,261,264,
	266,268,270,272,275,277,279,281,283,285,288,290,292,294,296,299,301,303,305,307,310,312,314,316,318,321,323,325,327,329,332,334,336,338,340,343,
	345,347,349,351,354,356,358,360,362,365,367,369,371,373,376,378,380,382,384,387,389,391,393,395,397,400,402,404,406,408,411,413,415,417,419,422,
	424,426,428,430,433,435,437,439,441,444,446,448,450,452,455,457,459,461,463,466,468,470,472,474,477,479,481,483,485,488,490,492,494,496,499,501,
	503,505,507,509,512,514,516,518,520,523,525,527,529,531,534,536,538,540,542,545,547,549,551,553,556,558,560
};
#define ADC_TARGET(a) (pgm_read_word_near(ADC_TARGET_VALUES + a))

/* Count the number of values that we have discarded.
 * Every time we switch from one channel to the other, we need to discard at least one
 * before trusting the reading.
 */
uint8_t adc_discard = 0;

/* Forward declaration */
uint8_t adc_choose_nextchannel(void);


/*
 * Configure the Analog-Digital Converter.
 */
void init_adc(void)
{
	/* Set the voltage reference to 2.56V and select a channel */
	ADMUX = ADMUX_RED;
	/* This bit needs to be set for the 2.56 Voltage reference */
	ADCSRB = (1 << REFS2);

	/* Set the prescaler to DIV64. The ADC clock will run @125kHz
	 * which is in the recommended range (50kHz to 200kHz).
	 * 1 ADC clockcycle will be 8uS.
	 * Sampling will be done 1.5 cycles * 8uS = 12uS after the start of a conversion.
	 * Result will be available 13 cycles * 8us = 104uS after the start of a conversion.
	 */
	ADCSRA = (1 << ADPS2) | (1 << ADPS1)
	/* Enable interrupts for ADC result */
		| (1 << ADIE)
	/* Enable the ADC */
		| (1 << ADEN);
}

/*
 * This function checks to see if the ADS is available and starts a new conversion on the right channel.
 */
void adc_loop(void)
{
	/*
	 * If the ADC is available, and if the signals have been on for at least a few cycles,
	 * then we can choose one channel and run a conversion.
	 */
	if ((ADCSRA & (1 << ADSC)) == 0 && pwm_c > 0x10) {
		/* Choosing the right channel is actually pretty complicated so we use a truth table */
		uint8_t next_channel = adc_choose_nextchannel();

		if (next_channel == ADMUX) {
			/* We stay on the same ADC channel - Just restart a new conversion */
			ADCSRA |= (1 << ADSC);
		}
		else if (next_channel != 0) {
			/* Change of ADC channel. We will need to discard. */
			adc_discard = 0;
			ADMUX = next_channel;
		}
	}
}

/*
 * Calculate the input to the truth table (read description above).
 *
 * Returns 0 if no ADC should be chosen or the ADMUX value to use.
 */
uint8_t adc_choose_nextchannel(void)
{
	uint8_t truth;
	if (ADMUX == ADMUX_RED)		truth = 0x00;
	if (ADMUX == ADMUX_GREEN)	truth = 0x10;
	if (ADMUX == ADMUX_BLUE)	truth = 0x20;

	if (adc_discard > 1)
		truth |= 0x8;
	if (pwm_c < pwm_red)
		truth |= 0x4;
	if (pwm_c < pwm_green)
		truth |= 0x2;
	if (pwm_c < pwm_blue)
		truth |= 0x1;

	return pgm_read_word_near(ADC_TRUTHTABLE + truth);
}

/*
 * This function gets and ADC reading and adjust the current PWM to get the current we want.
 *
 * This will be called 104 uS after the conversion is started above
 * but the measure is taken a t0+8uS so we can effectively measure
 * even when the PWM is only at a value of 1*8uS.
 *
 * If the brightness is at 0x01 (worst case) and the correct pwm at 0xFF (worst case), it will
 * take 2ms * 0xFF = 510ms for the current to reach the correct value.
 *
 * convSpeed = max(1, brightness * 8uS / 104uS)
 *  -> We can convert convSpeed times per each brightness cycle
 * stabilizeTime = NumberOfConversionsNeeded / convSpeed * 2mS
 *  -> NumberOfConversionsNeeded = 0xFF if we start @0 but we could start higher
 *
 * With brightness 0x01: 510mS
 * With brightness 0x02: 510mS
 * With brightness 0x20: 255mS
 * With brightness 0x80: 56mS
 * With brightness 0xFF: 26ms
 *
 */
void process_adc_reading(uint16_t adc)
{
	/* We always need to discard one measure */
	if (adc_discard++ < 1)
		return;

	if (ADMUX == ADMUX_RED) {
		if (adc < ADC_TARGET(redcpwm) && redcpwm < CPWM_MAX) {
			redcpwm++;
		}
		else if (redcpwm > CPWM_MIN) {
			redcpwm--;
		}
	}
	if (ADMUX == ADMUX_GREEN) {
		if (adc < ADC_TARGET(greencpwm) && greencpwm < CPWM_MAX) {
			greencpwm++;
		}
		else if (greencpwm > CPWM_MIN) {
			greencpwm--;
		}
	}
	if (ADMUX == ADMUX_BLUE) {
		/* Remember that the blue output is inverted */
		if (adc < ADC_TARGET(0xFF - bluecpwm) && bluecpwm > CPWM_MIN) {
			bluecpwm--;
		}
		else if (bluecpwm < CPWM_MAX) {
			bluecpwm++;
		}
	}
}

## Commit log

2012-07-17 Adding file as they were submitted to Laen PCB order
    [board.brd, board.sch]
2012-07-17 Adding bom
    [bom.tsv]
2012-07-26 Adding v0.2 files for motherboard - sent to fab
    [illumi-motherboard.brd, illumi-motherboard.sch]
2012-08-23 Adding files for v0.0/v0.1/v0.2
    [illumi-leddriver.brd, illumi-leddriver.sch, illumi-motherboard.brd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]
2012-08-23 Adding readme - some cleaning up (more to come)
    [board.brd, board.sch, bom.tsv]
2012-08-23 More cleanup + Adding LTSpice file
    [illumi-motherboard.brd, illumi-motherboard.sch]
2012-10-02 long time due commit with 0.3 and 0.4 and lots of work on the firmware
    [loochi-0.3a.brd, loochi-0.3a.sch, loochi-0.4.brd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]
2012-10-03 SPI slave working
2012-10-04 SPI-slave working with 3 bytes messages and re-synchronization with sender (based on timeout)
2012-10-05 For the first time, this firmware is able to control three channels. I have only tested one but there is no reason that the two others should not work. This is a major step forward! Also done a lot o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
    [adc.c, brightness.c, current.c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]
2012-10-10 Code works on the real board
2012-10-26 Adding bom to loochi 0.4
    [bom-0.4.xlsx]
2012-10-31 Adding STL files for latest version of the shade and plastic enclosing
    [Bridge_E.STL, ShadeMount_E.STL]
2012-10-31 Adding v10 of the firmware with support of the hardware button (ooh-yeah!)
2012-10-31 Button turns the light on and off
2012-10-31 Plastic design version E for SLA
    [Bridge_E.STL, HeatSink_E.STL, ShadeMount_E.STL]
2012-11-06 Added program 11-pwmadc-remote which allows full external control of the RED current PWM through the SPI interface and reading back the ADC values.
    This is useful to make sure that the ADC is working properly and to check the math that we use to convert ADC reading into actual current in the LED.
2012-11-15 Adding base Loochi 0.5 files
    [loochi-0.5.brd, loochi-0.5.sch]
2012-11-15 Finalized board layout but have not run DRC yet.
    [loochi-0.5.brd, loochi-0.5.sch]
2012-11-19 Continued work on board v0.5 - Integrated Jurgen v0.5.1 changes - Shielded bsense - Holes for lenses - drc ok now
    Next steps: BOM & check parts footprint
    [loochi-0.5.brd]
2012-11-19 More work on the board - almost final (antenna trace needs rework)
    [loochi-0.5.brd, loochi-0.5.sch]
2012-11-21 Commiting board 0.5 as ordered from Oshpark.com
    [loochi-0.5.brd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]
2012-11-21 Adding OpenOffice file for inductor size estimation
    [loochi-inductor-choice.ods]
2012-11-21 Adding CAM job file used to generate gerbers
2012-11-23 Moved two traces to match Sunstone PCB guidelines
    [loochi-0.5.brd]
2012-12-04 First draft of Loochi 0.6 - Back to BLE112 module - New power connector layout - New switch layout - One diode to make sure that the programmers can not provide power to the led - Another diode to pr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
    [loochi-0.6.brd, loochi-0.6.sch]
2013-01-02 One major fix (vias under the cpu removed) + minor adjustments
    * Removed all vias under the CPU
    * Fix holes for the lense
    * Fix size of power supply tab
    * Connect the button to the BLE Module
    [loochi-0.6.brd]
2013-01-02 Routed connections + Added SPI on BLE connector + Some cleaning/Rework
    [loochi-0.6.brd, loochi-0.6.sch]
2013-01-06 Final changes before ordering the board (minor cosmetic changes)
    [loochi-0.6.brd, loochi-0.6.sch]
2013-01-15 Fixing reference of F1 (we want a 0603)
    [loochi-0.6.brd, loochi-0.6.sch]
2013-01-15 Changed f-pwm to 250khz
2013-01-15 Switched to 250khz - Added adc test results
2013-01-15 Adding laen pcb files (gerber + render) for loochi 0.6
    [loochi-0.6.drills.xln]
2013-04-09 Added support for the Chip Select wire
2013-04-09 PCB 0.6b with some extra labels on the board for SPI debugging
    [loochi-0.6b.brd, loochi-0.6b.sch]
2013-04-09 adding first try at remodeling loochi in inventor fusion - not done at all ...
    [loochi.f3d]
2016-01-23 Adding woochi - a wifi loochi - wip from 2012
    [woochi.brd, woochi.sch]

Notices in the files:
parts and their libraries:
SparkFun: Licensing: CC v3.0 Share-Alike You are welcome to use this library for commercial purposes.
